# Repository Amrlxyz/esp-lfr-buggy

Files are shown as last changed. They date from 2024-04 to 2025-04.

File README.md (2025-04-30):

# ESP Line Following Robot

**GROUP 48:** 2nd Year Embedded Systems Project (ESP) 2023/24.

Project is in collaboration with 5 teammates: 
- [@Amrlxyz (me)](https://github.com/Amrlxyz) : Main Programmer + 3D CAD Designer 
- [@Hubr1z](https://github.com/Hubr1z) : 2nd Programmer
- [@Sarahelma](https://github.com/Sarahelma) : PCB Designer
- [@nishoujiwojiubuhuine](https://github.com/nishoujiwojiubuhuine) : 3rd Programmer + General Tech 
- [@Giselle-zheng](https://github.com/Giselle-zheng) : Wiring and Electrical

## Gallery

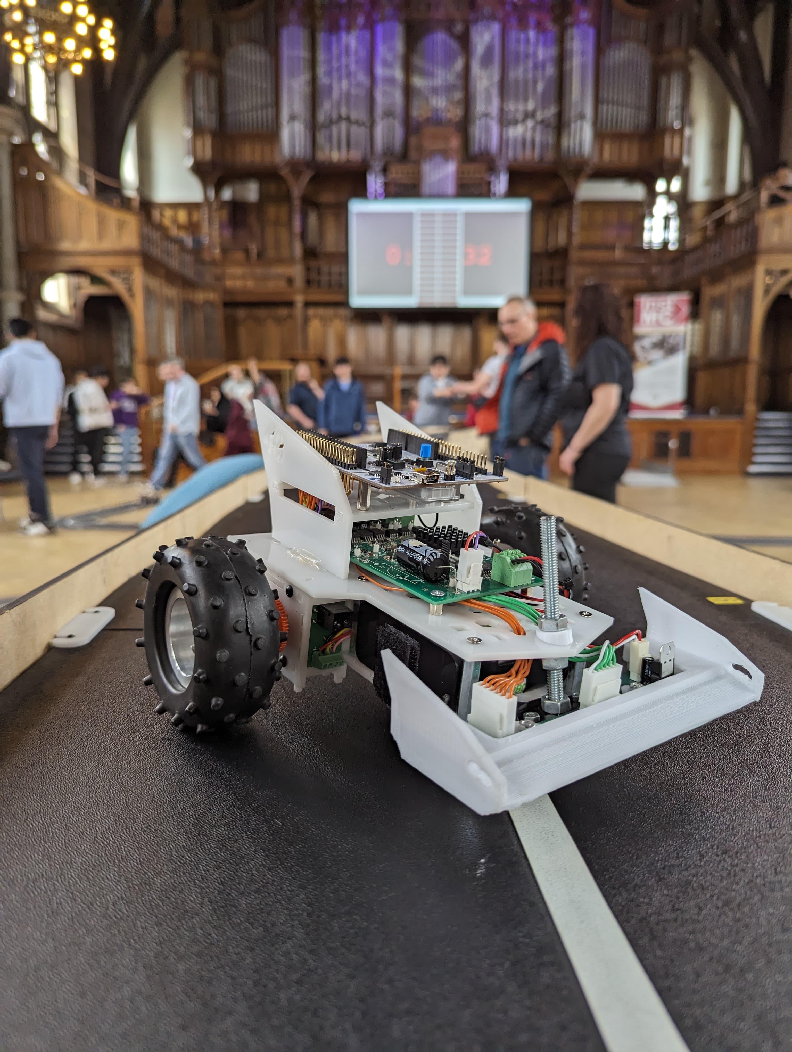
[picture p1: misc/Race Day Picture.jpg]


*Buggy Picture on the final race day*

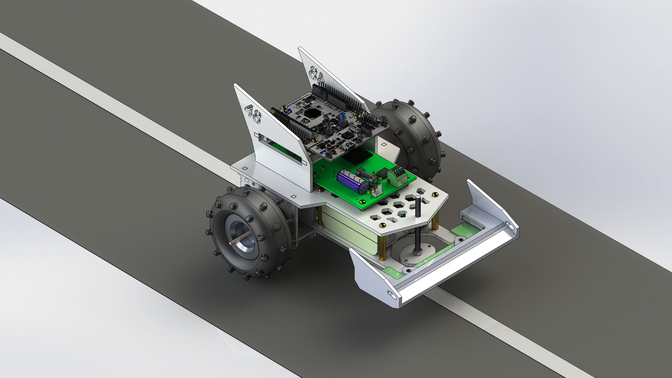
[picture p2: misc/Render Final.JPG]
Buggy Render


*Final Buggy Render Using SolidWorks*

## Achievements

- **ESP 2023/24 Final Race Winner !!!**
- 100% for TDA (Techincal Demonstration A)
- 100% for TDB (Techincal Demonstration B)
- 100% for TDC (Techincal Demonstration C)

## Features

- Mbed v5.15
- Nucleo STM32F401RE 
- Custom Sensor Array PCB
- Array of 6x TCRT5000 IR sensor for line following
- Custom CAD Model Designed in Solidworks

## API Documentation

Link to documentation: [Github Pages](https://amrlxyz.github.io/esp-lfr-buggy/)

## How to Use

### Flashing the MCU

1. Use the wiring diagram to connect the components.
2. Clone the project directly to Keil Studio Cloud.
3. Compile and flash on to the microcontroller.
4. Control the buggy using Bluetooth commands.

### How to run

1. Connect BLE to a phone
2. Place the whole sensor array in the black area of the track
3. Send "calibrate" Command
4. Wait until message is recieved on the phone
5. Place the buggy in the middle of the line
6. Send "line_follow" Command

## Buggy Commands

### Setup

1. Use "Serial Bluetooth Terminal" app on Android
2. Settings -> Send -> Newline -> None
3. Send Commands

### Command Format 

[2/3 Capital Letters] [optional value for certain commands] ['/' -> end character]

Full command list is in main.cpp

__Examples:__

EC/ -> "Execute" "Calibrate"

EF/ -> "Execute" "line_follow"

GSB/ -> Get the speed of both motors

## Linkedin Article

[Article Link](https://www.linkedin.com/pulse/2nd-year-embedded-systems-project-final-race-winner-hakeem-jfuzf)

I might have mentioned a follow-up technical write-up at the end... but life (and distractions) keep happening. We'll see.

## Hello Future UoM 2nd Yr EEE Students

Feel free to use this code as inspiration (at your own risk). Looking back, definitely there are ways to improve it.

If you find the code helpful, feel free to drop a star ⭐ on the repo _(I crave external validation)_

Goodluck!

## Dependencies

Imported 3rd Party Mbed Libraries

- [Driver Board Onboard Battery Monitor](https://os.mbed.com/users/EmbeddedSam/code/Nucleo_F401RE_DS271_Battery_Monitor/) by Sam Walsh
- [QEI Library](https://os.mbed.com/cookbook/QEI) by Aron Berk

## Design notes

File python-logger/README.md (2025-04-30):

# Serial Data Processor

Captures data in the form of Comma Seperated Values from Serial and plots the graph.

This is extensively used for our ESP Line Following Robot / Buggy in which it was used to log and tune PID constants.

Currently, the usage of this code is currently limited only to the application of PID data.

However, adapting to different use case should be as simple as changing the variable names in the list.

## Features

- Automatic logging into a csv file into a /logs folder with date/time
- Live plot and latest data plot option

## Example Plots
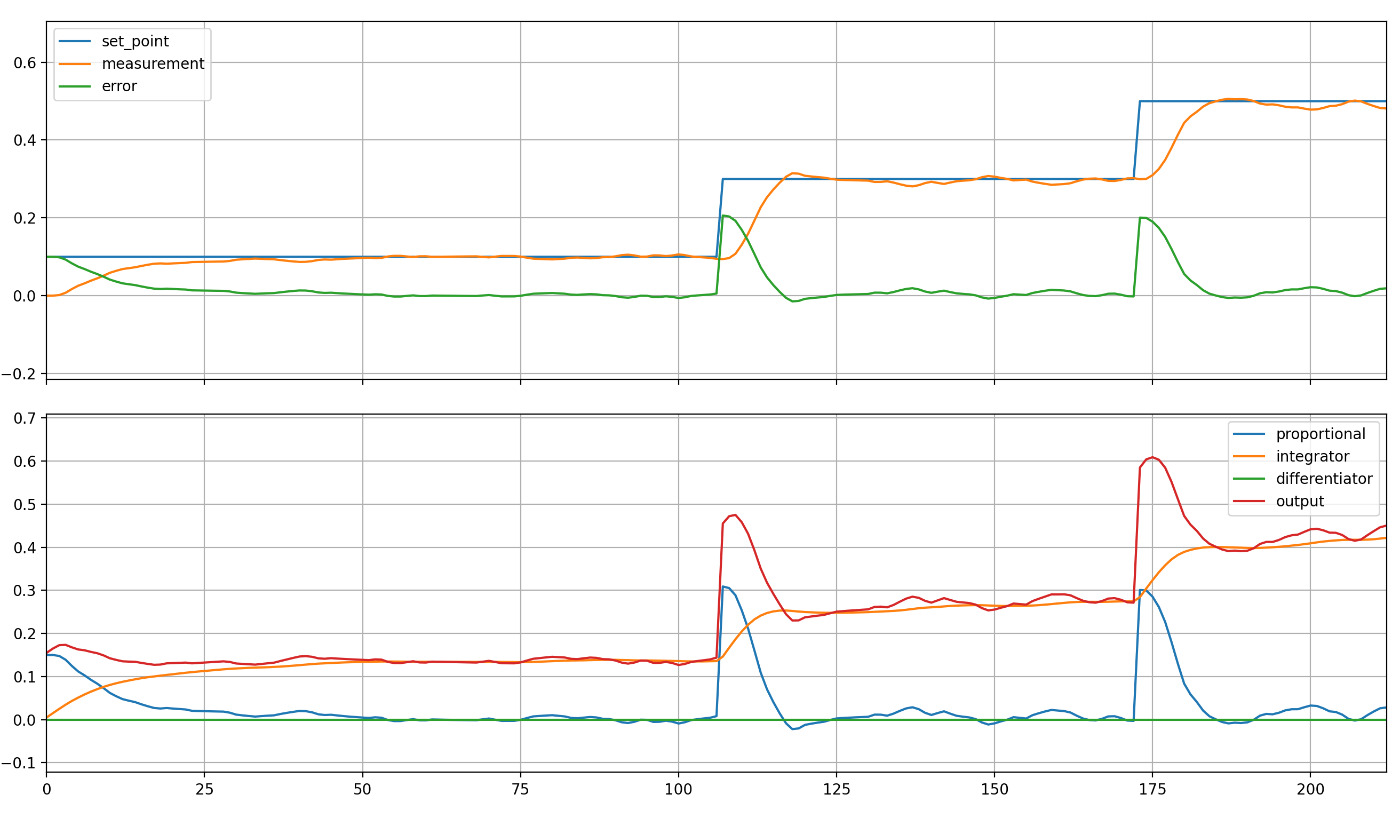
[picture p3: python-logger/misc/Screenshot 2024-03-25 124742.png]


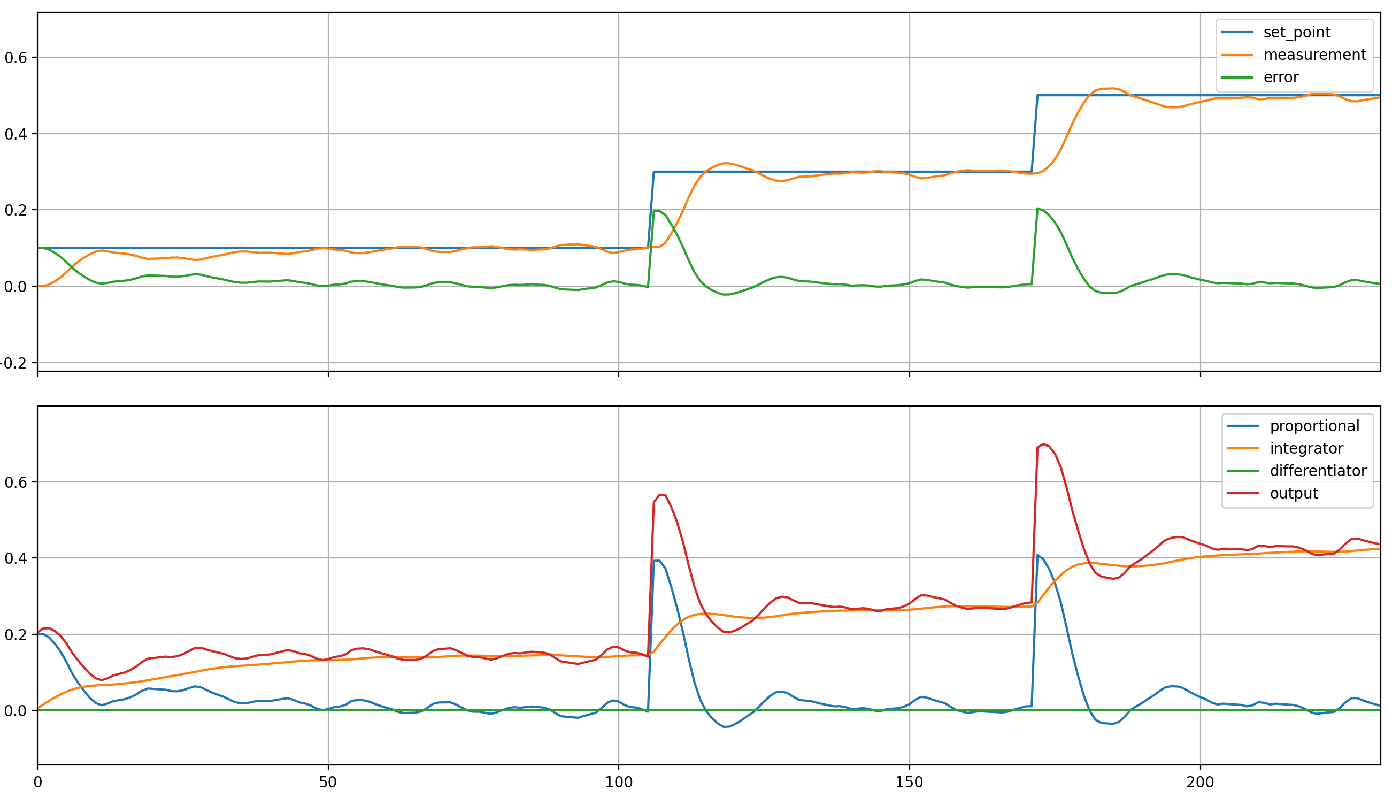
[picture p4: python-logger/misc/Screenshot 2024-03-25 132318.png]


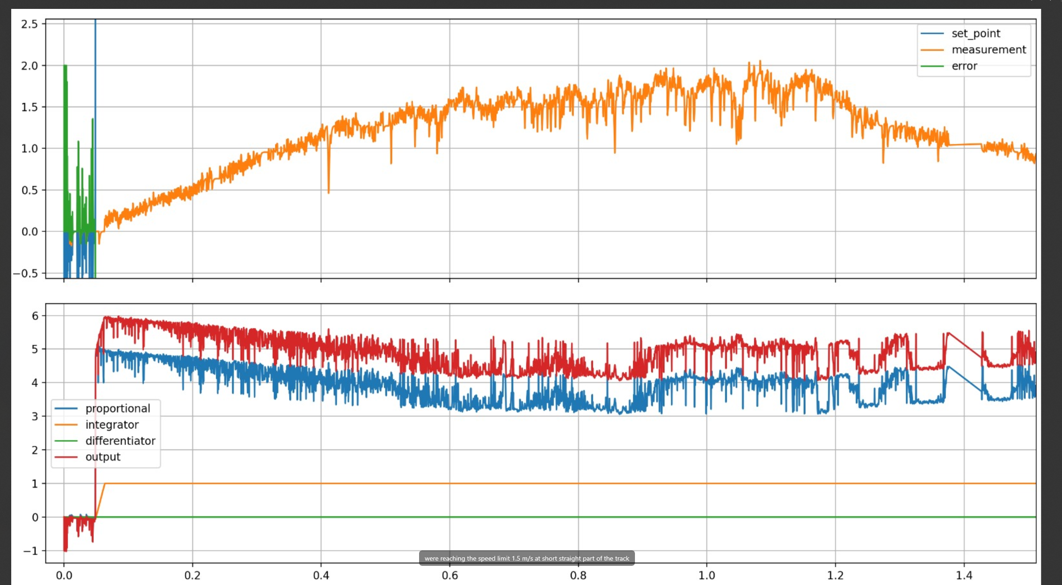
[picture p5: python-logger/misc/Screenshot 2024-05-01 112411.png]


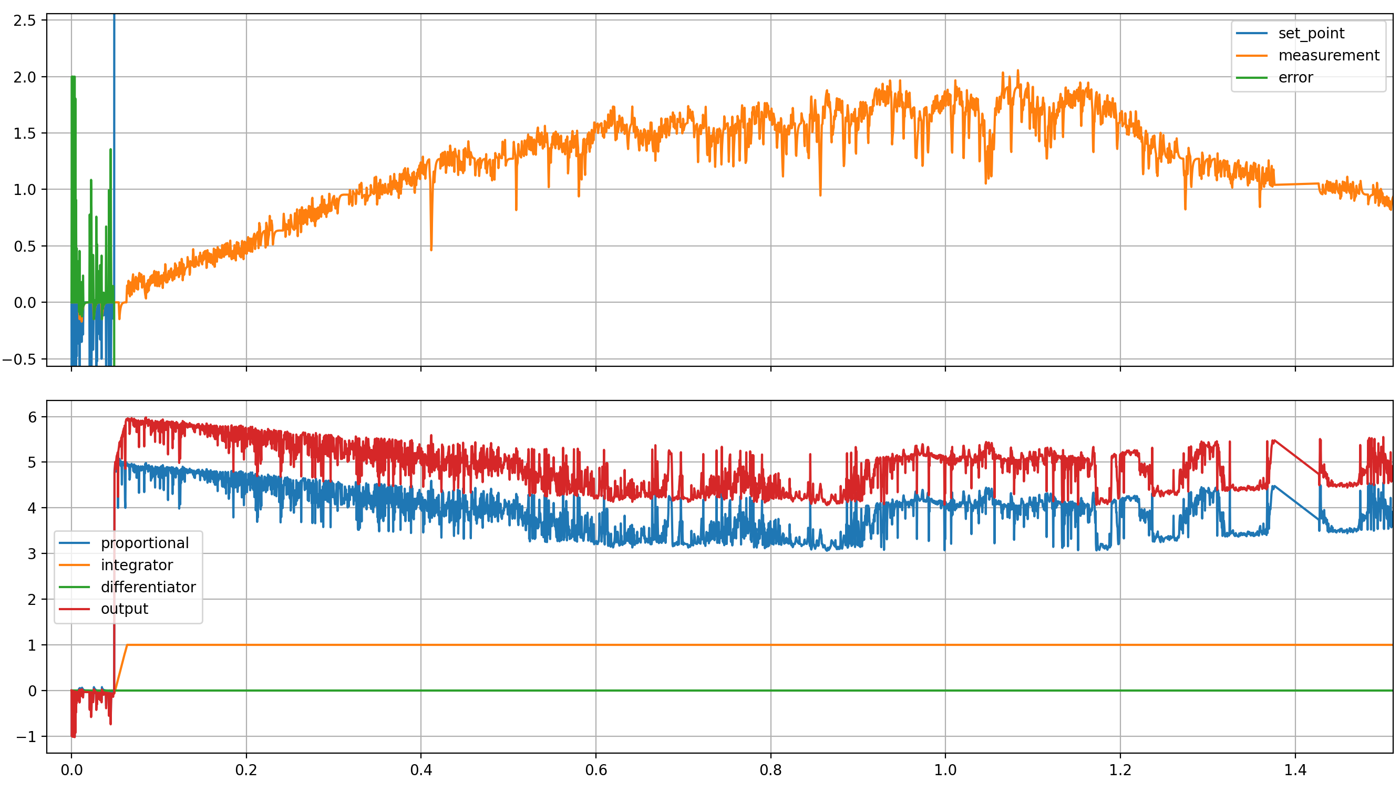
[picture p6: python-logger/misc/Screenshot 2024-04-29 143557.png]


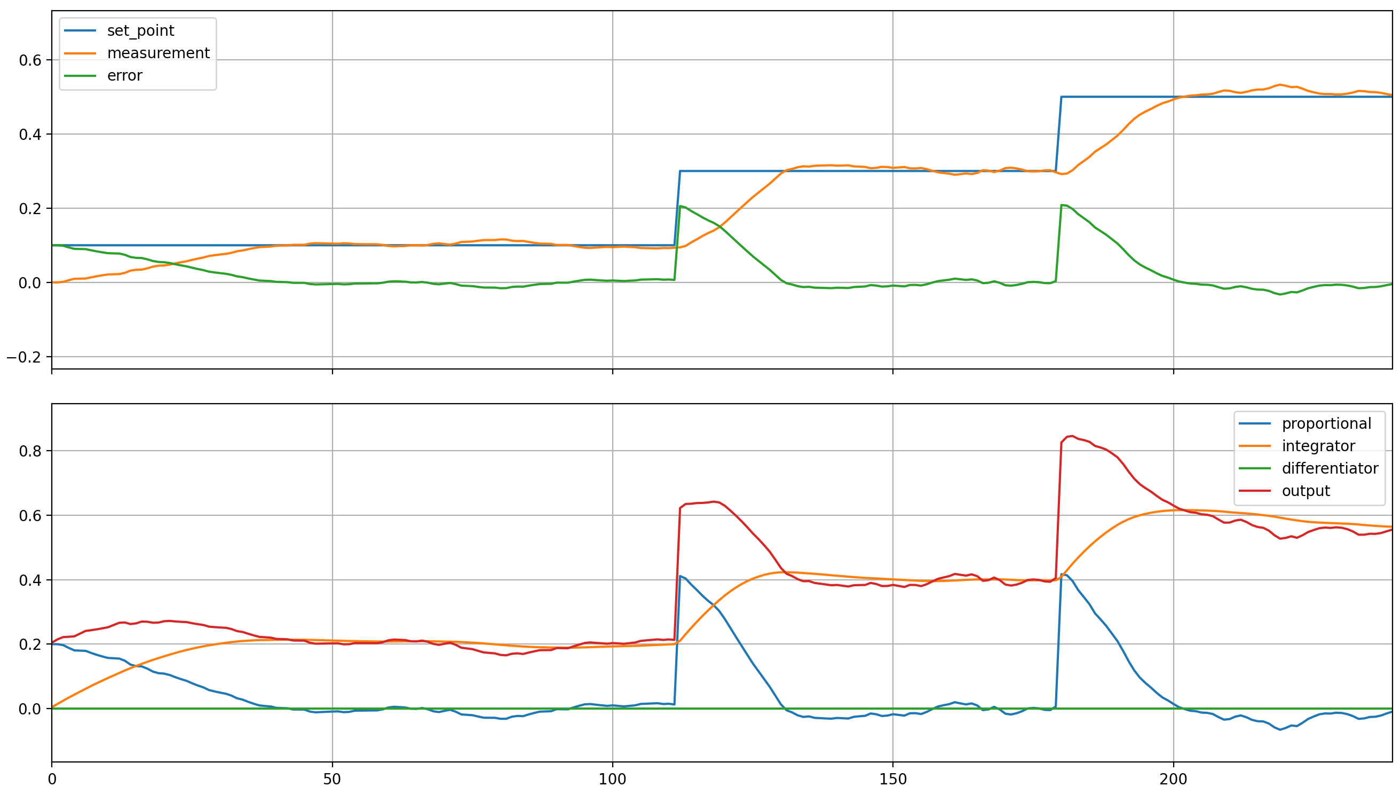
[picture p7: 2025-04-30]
python-logger/misc/Screenshot 2024-03-25 132233.png

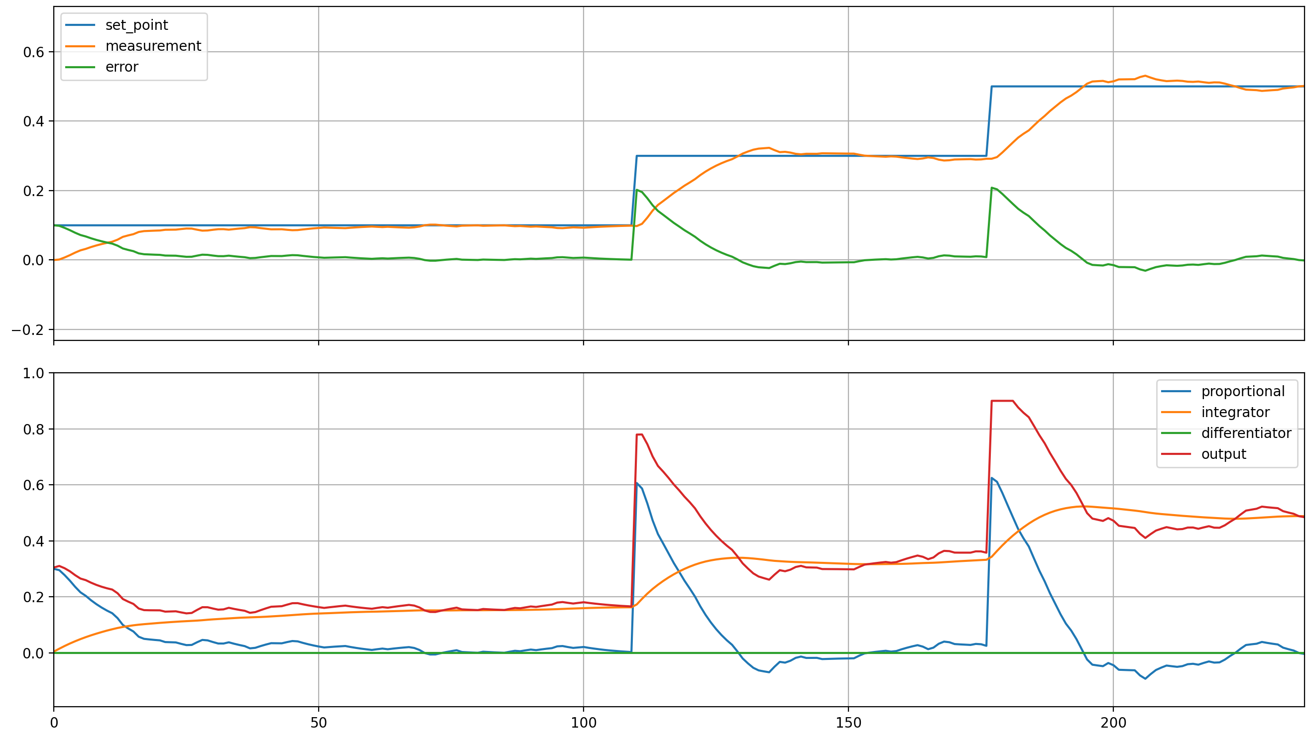
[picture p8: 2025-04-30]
python-logger/misc/Screenshot 2024-03-25 130755.png

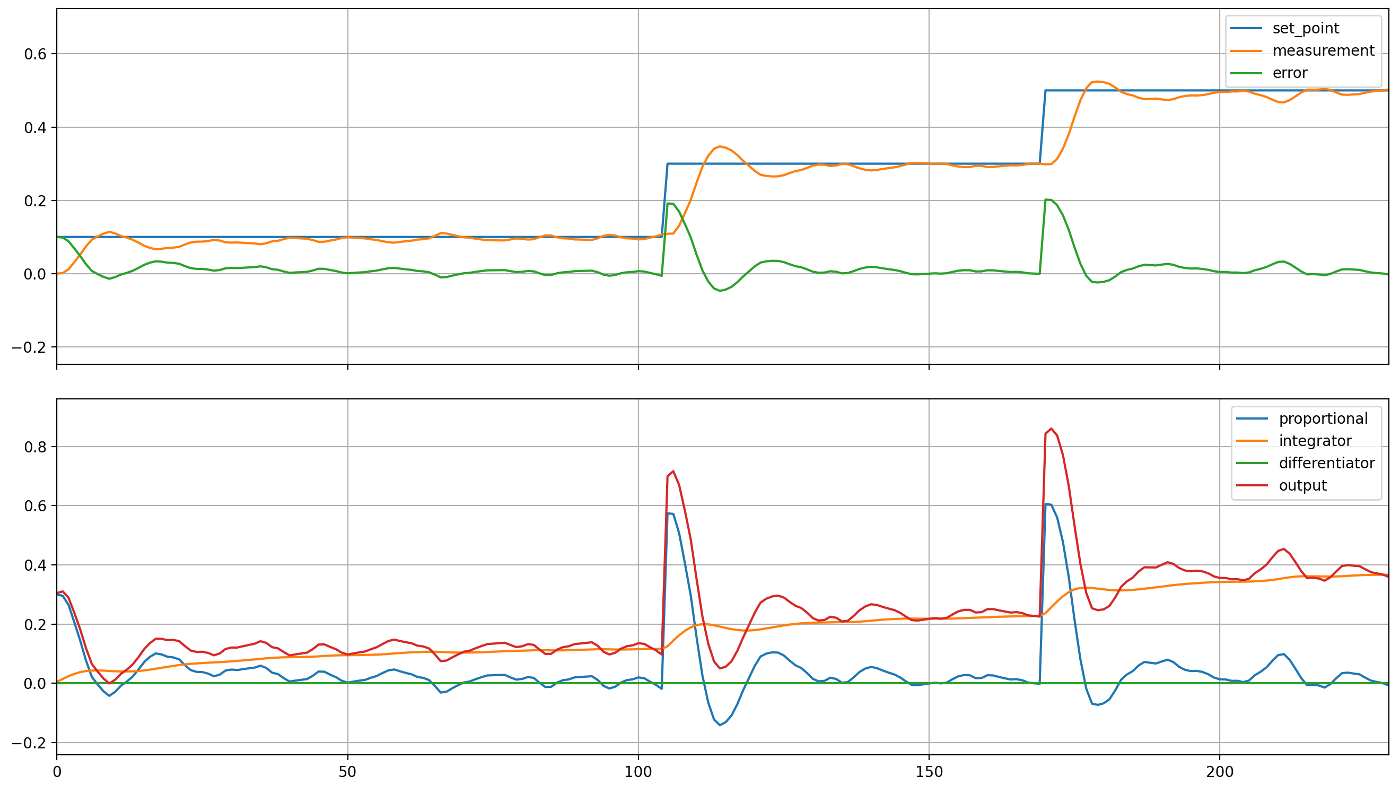
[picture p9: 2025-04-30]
python-logger/misc/Screenshot 2024-03-25 130914.png

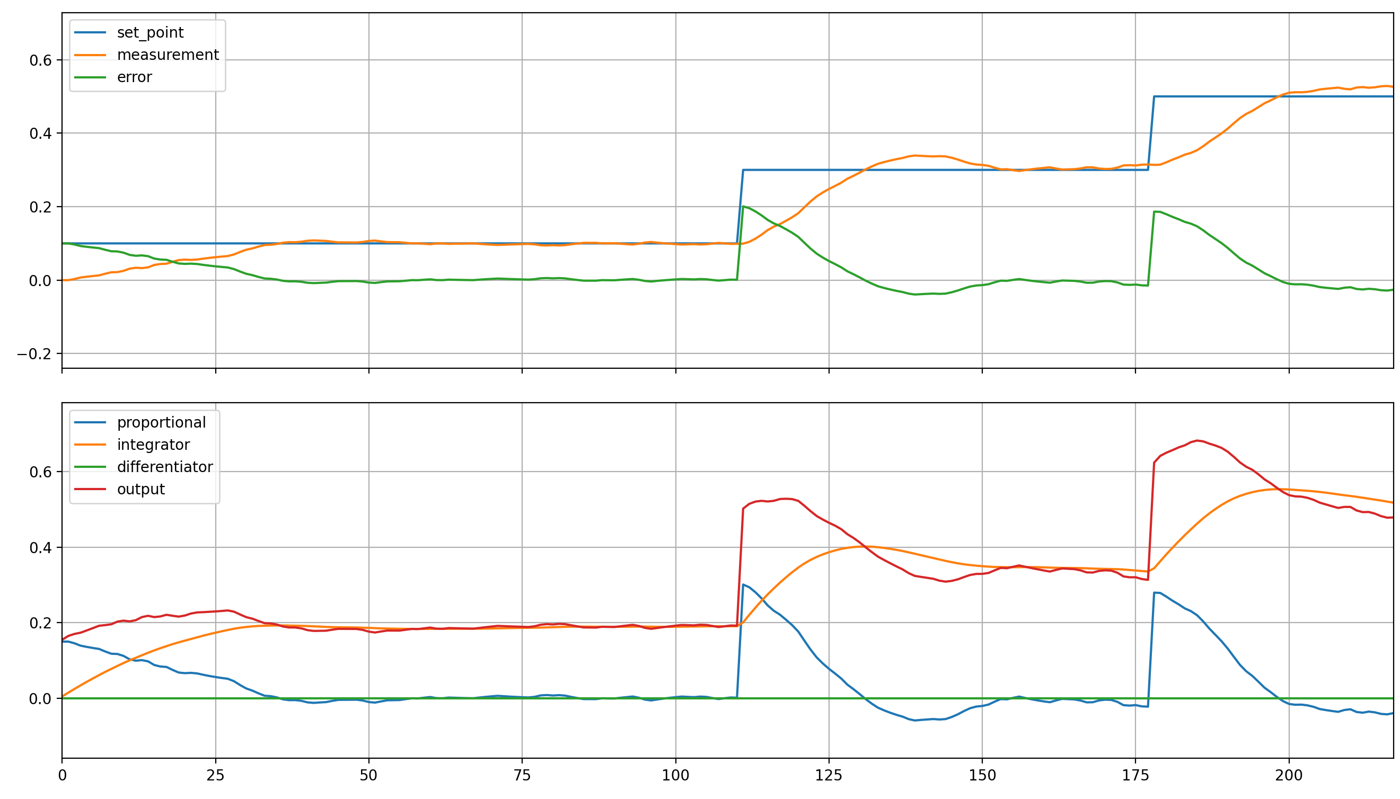
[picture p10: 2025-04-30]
python-logger/misc/Screenshot 2024-03-25 125631.png

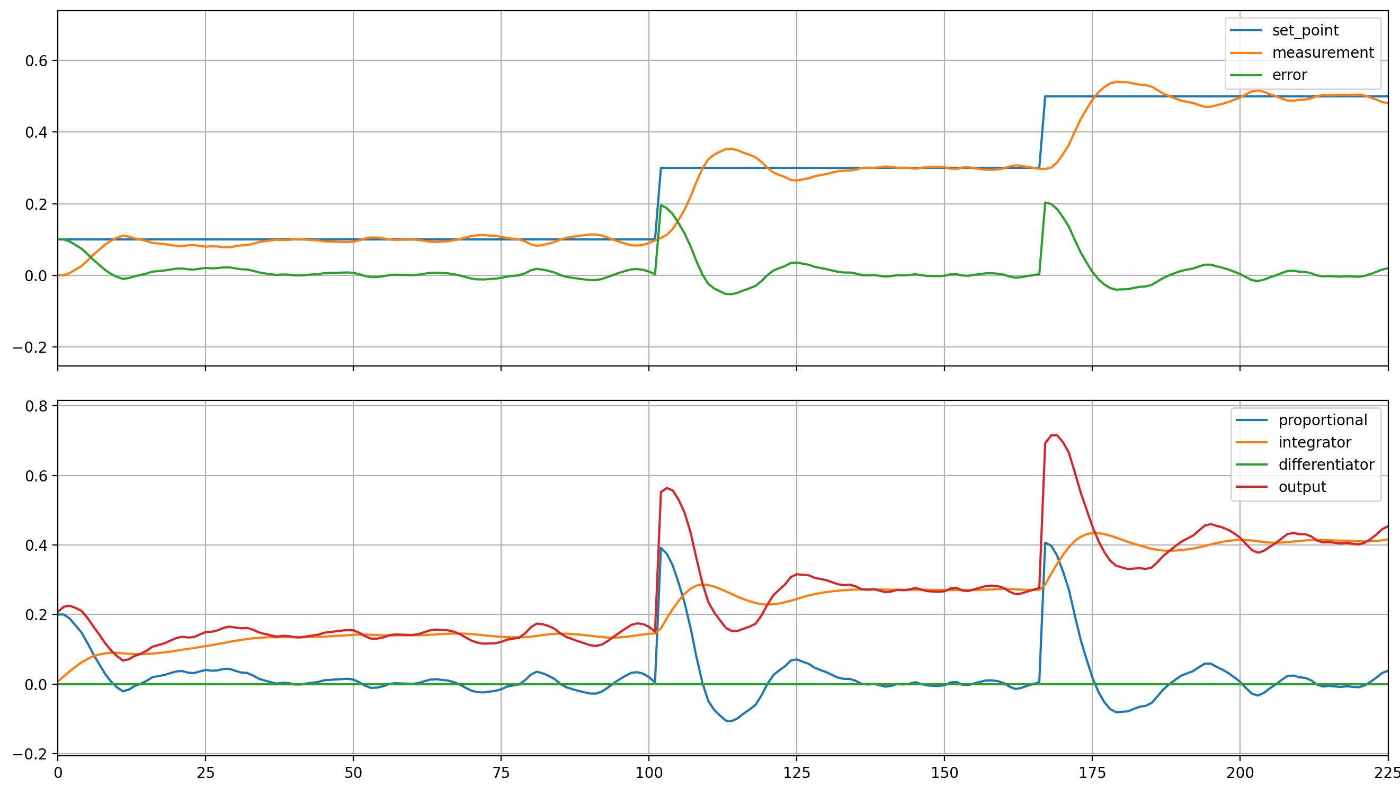
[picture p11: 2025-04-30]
python-logger/misc/Screenshot 2024-03-25 131515.png

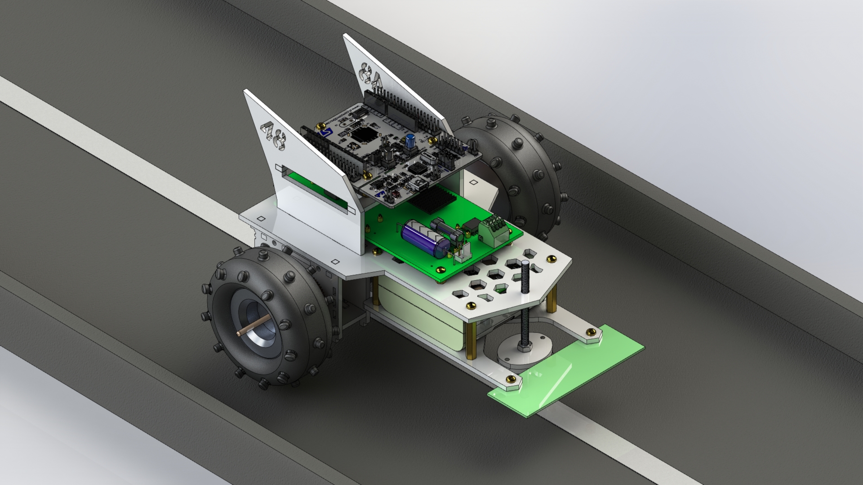
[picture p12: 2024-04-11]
misc/Buggy Render.JPG

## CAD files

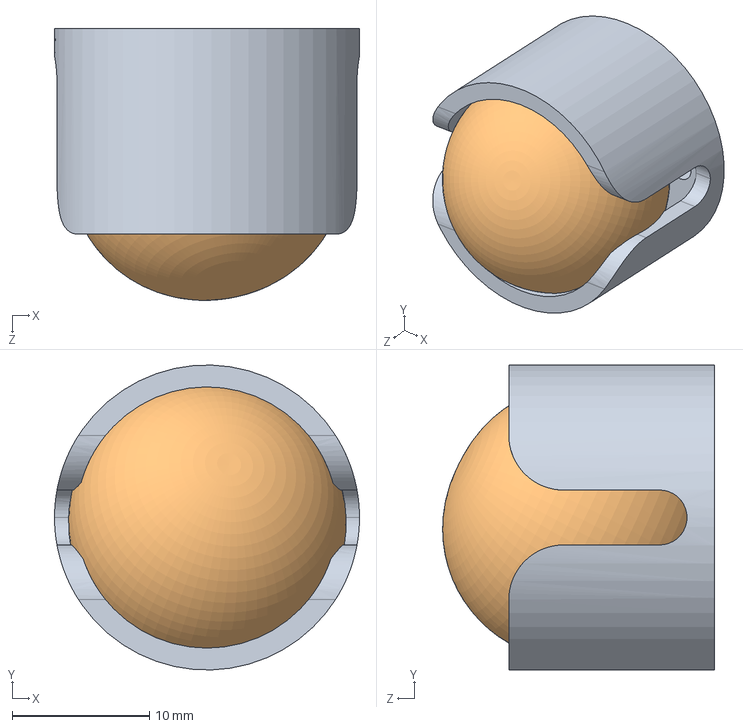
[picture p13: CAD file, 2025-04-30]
hardware/Buggy CAD/Buggy CAD v3/Castor_Assembly/Ball_Housing_Assembly.SLDASM
22.2 x 22.2 x 19.8 mm
Ball Housing
Ball

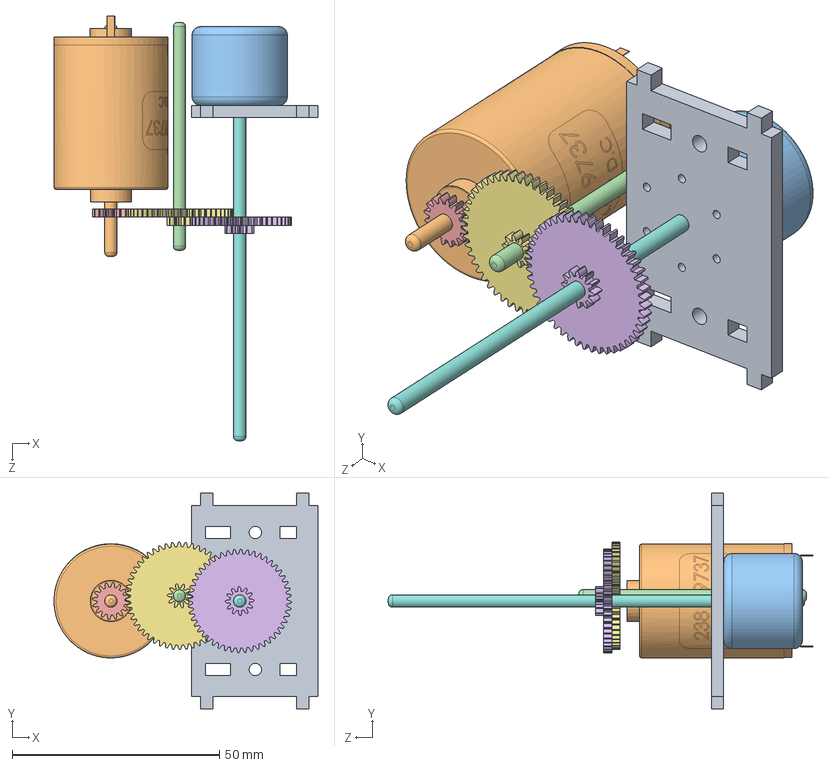
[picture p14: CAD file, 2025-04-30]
hardware/Buggy CAD/Buggy CAD v3/MOTOR_MODULE_2/Gbox Assy.SLDASM
63.8 x 52.1 x 102.5 mm
input side encoder half
Motor
ENCODER
intermediate_axle
spur gear_iso
Gear - 48_12(1)
Gear - 50_10(1)
Axle Long

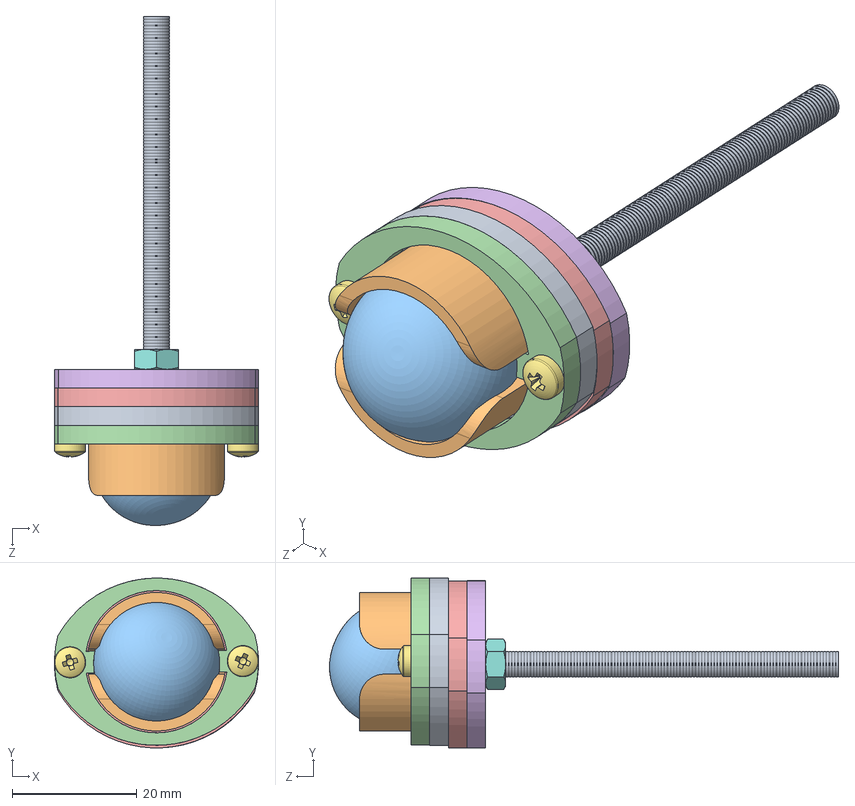
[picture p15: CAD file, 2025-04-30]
hardware/Buggy CAD/Buggy CAD v3/Castor_Assembly/Castor_Assembly.SLDASM
32.7 x 27.3 x 81.7 mm
Ball Housing
Ball
CastorHolder1
CastorHolder2
CastorHolder3
CastorHolder4
pan head cross recess screw_bsi x 2
hex nut style 1 gradeab_bsi
Rod

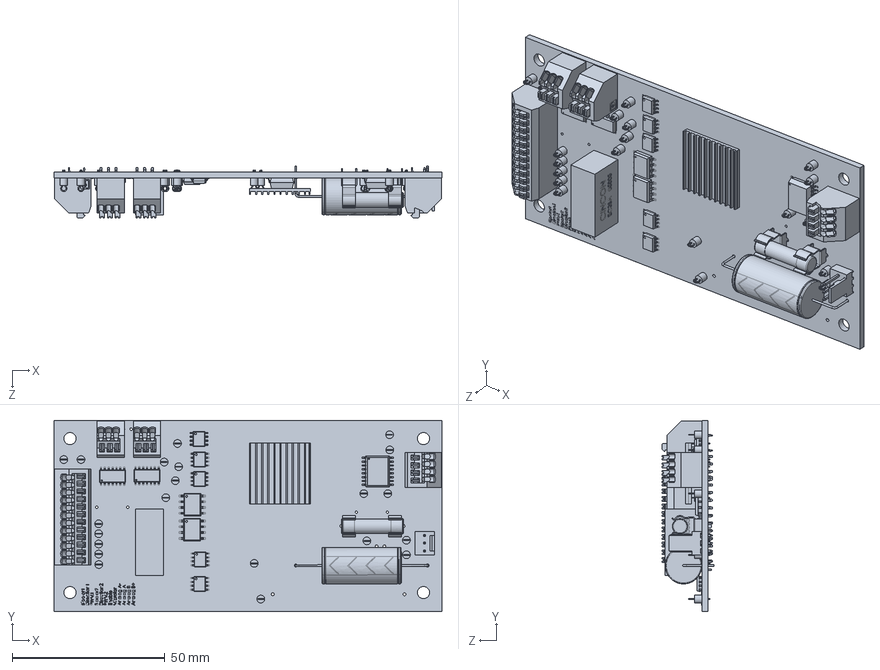
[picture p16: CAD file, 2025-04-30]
hardware/Buggy CAD/Buggy CAD v3/Motor Driver Board Full.SLDPRT
127.2 x 62.8 x 17.1 mm

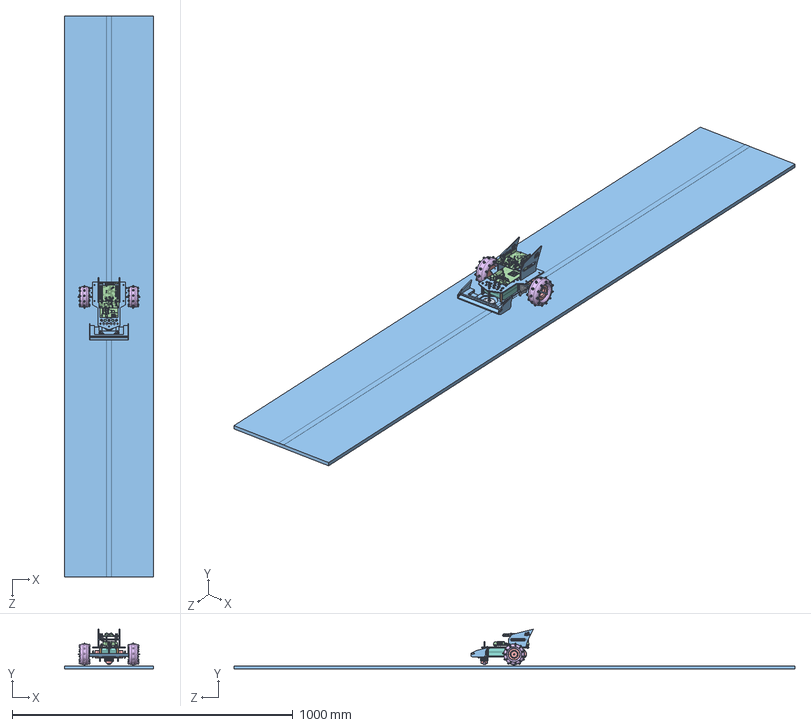
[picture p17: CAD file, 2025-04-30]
hardware/Buggy CAD/Buggy CAD v3/Final Assembly v3.SLDASM
317.0 x 141.8 x 2000.0 mm
Body V3
Motor Driver Board Full
Ball Housing
Ball
CastorHolder1
CastorHolder2
CastorHolder3
CastorHolder4
pan head cross recess screw_bsi x 2
hex nut style 1 gradeab_bsi
Rod
input side encoder half x 2
Motor x 2
ENCODER x 2
intermediate_axle x 2
spur gear_iso x 2
Gear - 48_12(1) x 2
Gear - 50_10(1) x 2
Axle Long x 2
NUCLEO-F401RE
Wheel_Without_Tyre x 2
Tyre(1)(1) x 2
5mm M3 Standoffs x 4
BatteryHolder8Way(1)
10mm M3 Standoffs x 3
30mm M3 Standoffs x 4
M3 Screw and Nut x 2

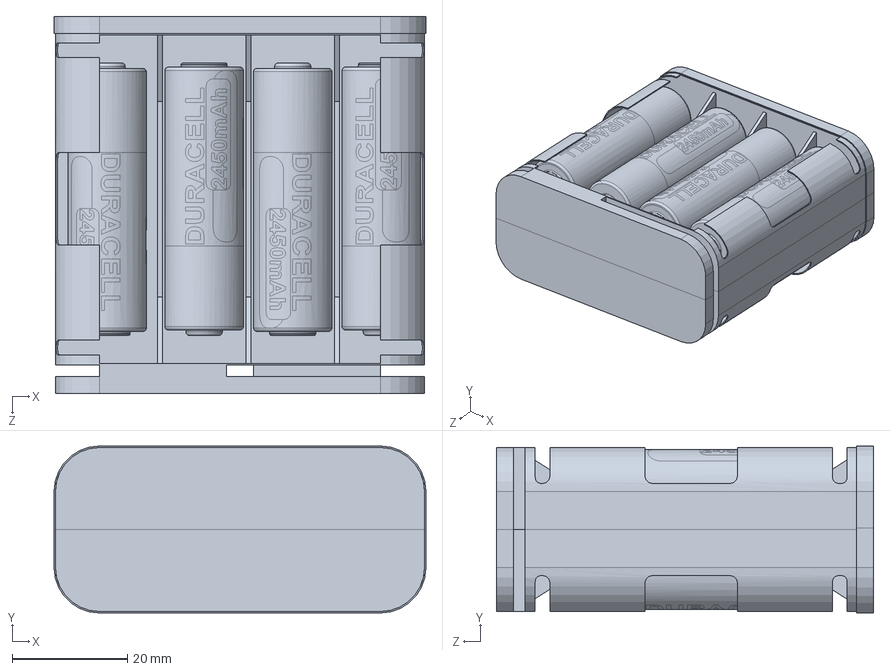
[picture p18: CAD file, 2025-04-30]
hardware/Buggy CAD/Buggy CAD v3/BatteryHolder8Way(1).SLDPRT
64.5 x 29.0 x 65.5 mm

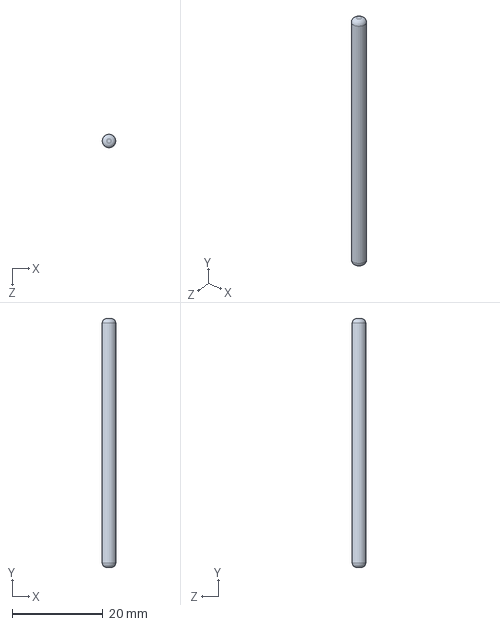
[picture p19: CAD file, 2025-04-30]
hardware/Buggy CAD/Buggy CAD v3/MOTOR_MODULE_2/intermediate_axle.SLDPRT
3.00 x 55.0 x 3.00 mm

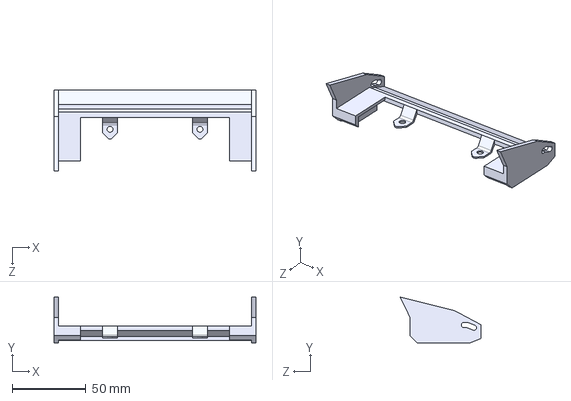
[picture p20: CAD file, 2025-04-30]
hardware/Buggy CAD/Buggy CAD v3/Printed/FrontWingBuggy.STEP
137.0 x 31.1 x 54.8 mm

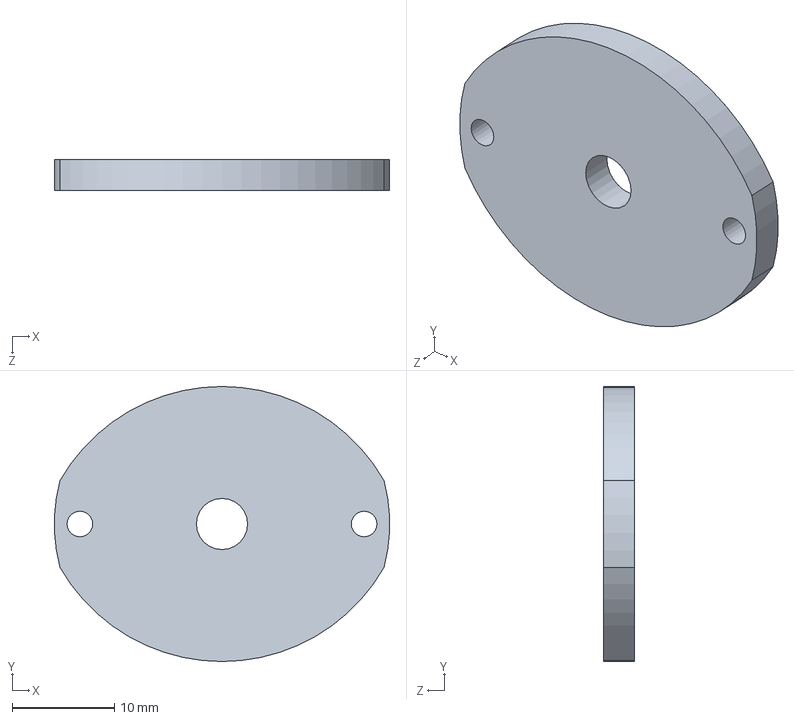
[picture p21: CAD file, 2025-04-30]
hardware/Buggy CAD/Buggy CAD v3/Castor_Assembly/CastorHolder4.SLDPRT
32.7 x 26.9 x 3.00 mm

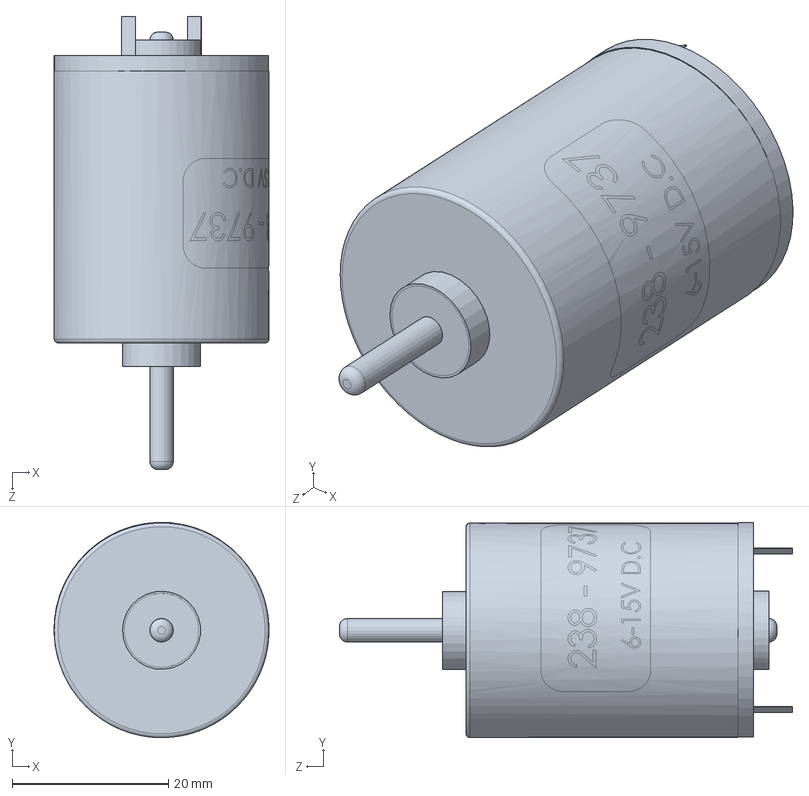
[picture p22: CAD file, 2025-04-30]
hardware/Buggy CAD/Buggy CAD v3/MOTOR_MODULE_2/Motor.SLDPRT
27.5 x 27.6 x 58.0 mm

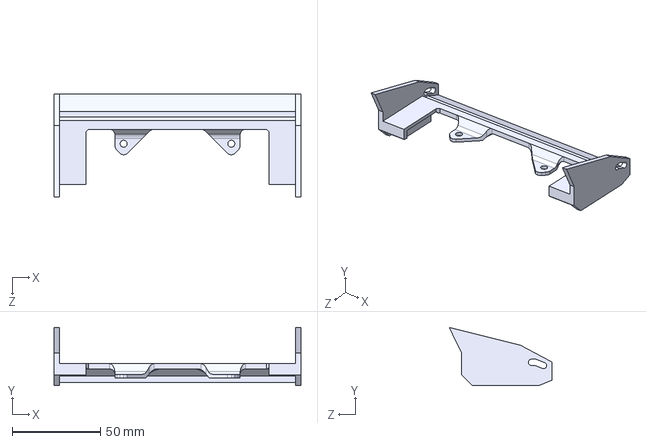
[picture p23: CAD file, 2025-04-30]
hardware/Buggy CAD/Buggy CAD v3/Printed/FrontWingBumper.STEP
140.0 x 33.0 x 58.2 mm

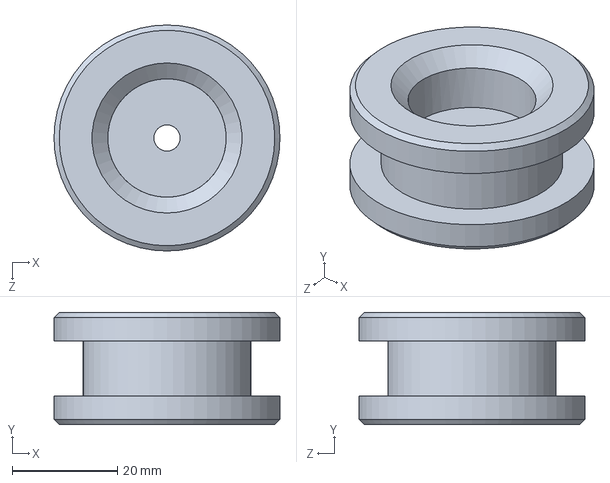
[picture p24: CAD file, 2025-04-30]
hardware/Buggy CAD/Buggy CAD v3/Wheel_Without_Tyre.SLDPRT
43.0 x 21.4 x 43.0 mm

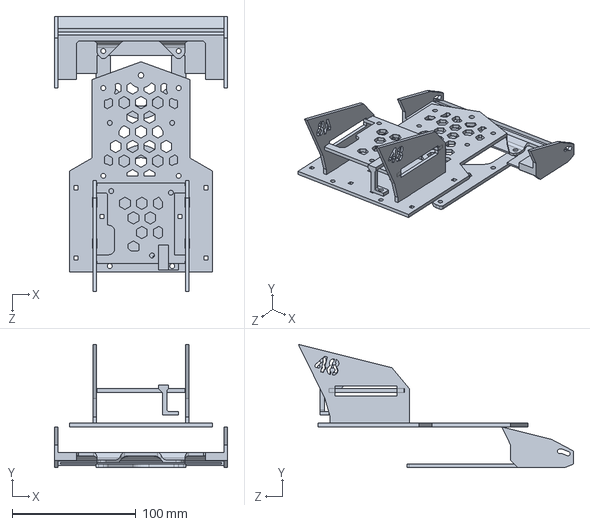
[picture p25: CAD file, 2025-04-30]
hardware/Buggy CAD/Buggy CAD v3/Body V3.SLDPRT
140.0 x 99.8 x 222.9 mm

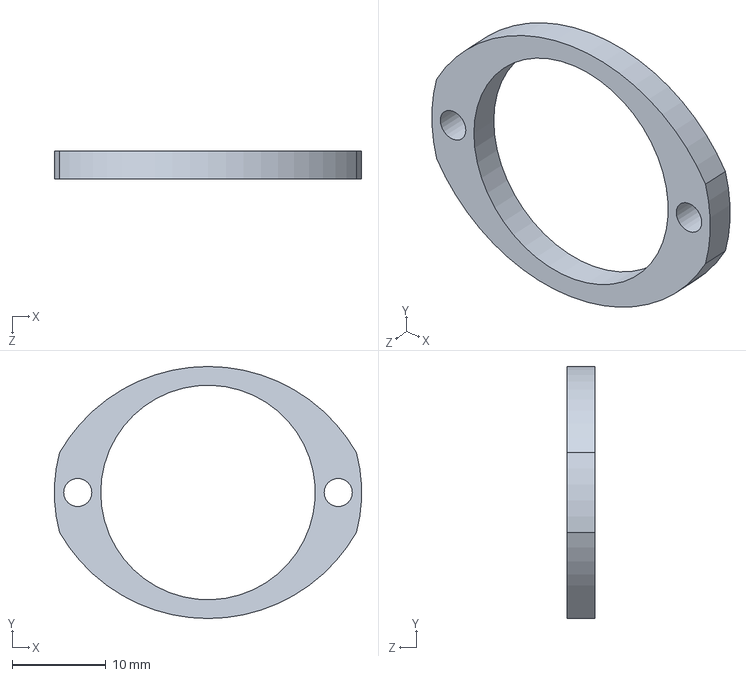
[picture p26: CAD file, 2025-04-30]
hardware/Buggy CAD/Buggy CAD v3/Castor_Assembly/CastorHolder1.SLDPRT
32.7 x 26.8 x 3.00 mm

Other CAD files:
hardware/Buggy CAD/Buggy CAD v3/Castor_Assembly/CastorHolder2.SLDPRT
hardware/Buggy CAD/Buggy CAD v3/Group_48_Holes_Fixed.DXF
hardware/Buggy CAD/Buggy CAD v3/MOTOR_MODULE_2/input side encoder half.SLDPRT
hardware/Buggy CAD/Buggy CAD v3/Printed/30_deg_ramp.STEP
hardware/Buggy CAD/Buggy CAD v1/10mm M3 Standoffs.SLDPRT
hardware/Buggy CAD/Buggy CAD v1/5mm M3 Standoffs.SLDPRT
hardware/Buggy CAD/Buggy CAD v1/Buggy Assembly v1.SLDASM
hardware/Buggy CAD/Buggy CAD v1/Castor_Assembly/Ball Housing.SLDPRT
hardware/Buggy CAD/Buggy CAD v1/Castor_Assembly/Ball.SLDPRT
hardware/Buggy CAD/Buggy CAD v1/Castor_Assembly/CastorHolder2.SLDPRT
hardware/Buggy CAD/Buggy CAD v1/Castor_Assembly/CastorHolder3.SLDPRT
hardware/Buggy CAD/Buggy CAD v1/Castor_Assembly/Castor_Assembly.SLDASM
hardware/Buggy CAD/Buggy CAD v1/Castor_Assembly/Rod.SLDPRT
hardware/Buggy CAD/Buggy CAD v1/Chassis Only.SLDPRT
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

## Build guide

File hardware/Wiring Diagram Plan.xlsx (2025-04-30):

 | LeftMCU
Pin No. | PIN LABEL | CONNECTION | PIN LABEL | CONNECTION
1 | PC_10 |  | PC_11
2 | PC_12 |  | PD_2
3 | VDD |  | E5V | 5V_3
4 | BOOT0 |  | GND | GND_3 |  | COLOR CODE
5 | NC |  | NC |  |  | LEFT (DARKER) | RIGHT
6 | NC |  | IOREF |  |  | LeftMCU | RightMCU
7 | PA_13 |  | RESET |  |  | MOTOR DRIVER
8 | PA_14 |  | 3V3 |  |  | MOTOR L | MOTOR2 R
9 | PA_15 (TIM2C1) |  | 5V | BT VCC |  | SENSOR BOARD
10 | GND |  | GND | BT GND |  | BLUETOOTH
11 | PB_7 |  | GND
12 | PC_13 | X | VIN
13 | PC_14 | X | NC
14 | PC_15 | X | PA_0 (TIM5C1) | CHA
15 | PH_0 | X | PA_1 (TIM5C2) | CHB
16 | PH_1 | X | PA_4 | IN3
17 | VBAT |  | PB_0 | IN4
18 | PC_2 | IN1 | PC_1 | IN5
19 | PC_3 | IN2 | PC_0 | IN6
 | RightMCU
Pin No. | PIN LABEL | CONNECTION | PIN LABEL | CONNECTION
1 | PC_9 |  | PC_8
2 | PB_8 |  | PC_6
3 | PB_9 |  | PC_5
4 | AVDD |  | U5V
5 | GND |  | NC
6 | PA_5 | USED BY LED | PA_12 | BT - TX
7 | PA_6 | JP1a_1 | PA_11 | BT - RX
8 | PA_7 | JP1a_2 | PB_12
9 | PB_6 | JP1a_3 | NC
10 | PC_7 | JP1a_4 | GND
11 | PA_9 | JP1a_5 | PB_2 | OUT1
12 | PA_8 | JP1a_6 | PB_1 | OUT2
13 | PB_10 | Enable | PB_15 | OUT3
14 | PB_4 | MicroLan | PB_14 | OUT4
15 | PB_5 |  | PB_13 | OUT5
16 | PB_3 (TIM2C2) | CHA | AGND
17 | PA_10 | CHB | PC_4 | OUT6
18 | PA_2 (TIM2C3) | X USART | NC
19 | PA_3 (TIM2C4) | X USART | NC
 | JP1a |  | JP8
Pin No. | PIN LABEL | CONNECTION | PIN LABEL | CONNECTION
1 | Bipolar 1 | PA_6 | 4 - Out1R | V+
2 | Direction 1 | PA_7 | 3 - Out1L | V-
3 | PWM 1 | PB_6 | 2 - Out2R | V+
4 | Bipolar 2 | PC_7 | 1 - Out2L | V-
5 | Direction 2 | PA_9
6 | PWM 2 | PA_8
7 | Enable | PB_10
8 | MicroLan | PB_4
9 | Analog A- | Not Important
10 | Analog A+ | Not Important
11 | Analog B- | Not Important
12 | Analog B- | Not Important
 | JP4 |  | JP5
Pin No. | PIN LABEL | CONNECTION | PIN LABEL | CONNECTION
1 | 5V_1 | Enc_5V | GND_1 | Enc_0V
2 | 5V_2 | Enc_5V | GND_2 | Enc_0V
3 | 5V_3 | 5V | GND_3 | GND
 | MOTORL |  | MOTORR
 | PIN LABEL | CONNECTION | PIN LABEL | CONNECTION
 | V+ | Out2R | V+ | Out1R
 | V- | Out2L | V- | Out1L
 | Enc_5V | 5V | Enc_5V | 5V
 | Enc_0V | GND | Enc_0V | GND
 | CHA | PA_2 (TIM2C3) | CHA | PA_0 (TIM5C3)
 | CHB | PA_3 (TIM2C4) | CHB | PA_1 (TIM2C4)
 | SENS_PWR
 | PIN LABEL | CONNECTION
 | 5V | 5V_3
 | GND | GND_3
 |  |  |  |  | Connect the flipped gearbox as if it is with flipped terminals
 | SENS_D_IN |  | SENS_A_OUT | NEEDS ADC
 | PIN LABEL | CONNECTION | PIN LABEL | CONNECTION
 | OUT1 | PB_2 | IN1 | PC_2
 | OUT2 | PB_1 | IN2 | PC_3
 | OUT3 | PB_15 | IN3 | PA_4
 | OUT4 | PB_14 | IN4 | PB_0
 | OUT5 | PB_13 | IN5 | PC_1
 | OUT6 | PC_4 | IN6 | PC_0

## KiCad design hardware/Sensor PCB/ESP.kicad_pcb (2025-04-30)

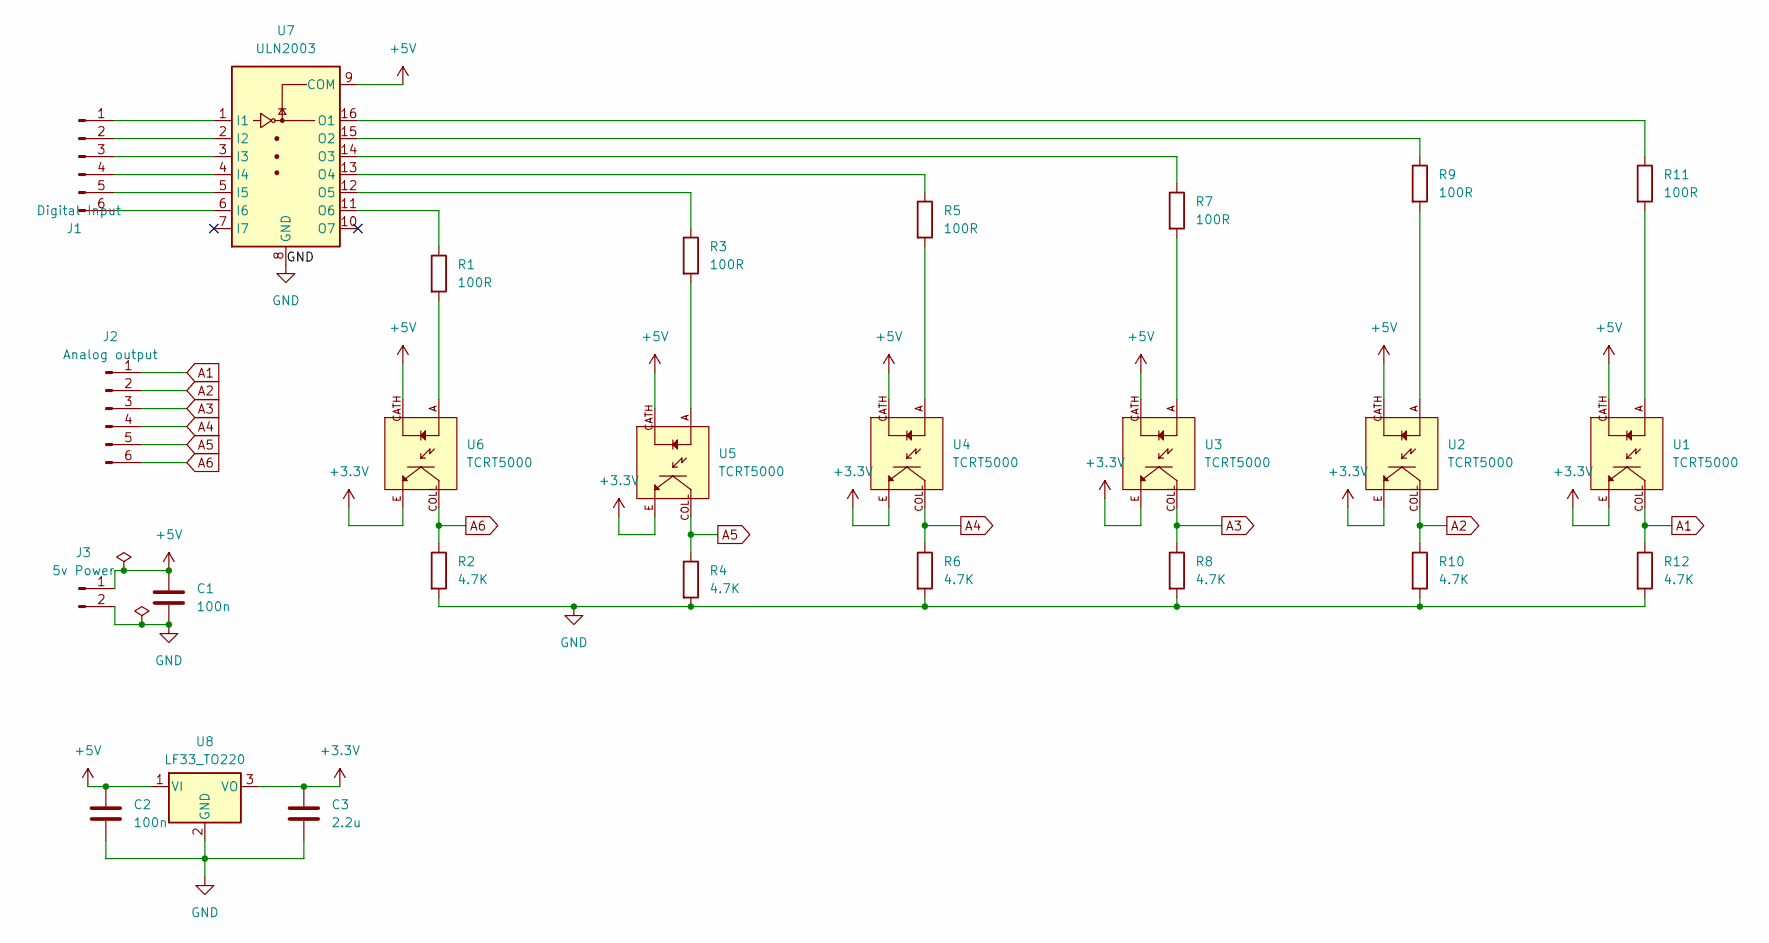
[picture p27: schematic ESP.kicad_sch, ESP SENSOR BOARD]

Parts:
C1, C2: 100n; CP_Radial_D5.0mm_P2.50mm
C3: 2.2u; CP_Radial_D5.0mm_P2.50mm
J1: Digital Input; JST_EH_B6B-EH-A_1x06_P2.50mm_Vertical
J2: Analog output; JST_EH_B6B-EH-A_1x06_P2.50mm_Vertical
J3: 5v Power; JST_ACH_BM02B-ACHSS-GAN-ETF_1x02-1MP_P1.20mm_Vertical
R1, R3, R5, R7, R9: 100R; R_Axial_DIN0207_L6.3mm_D2.5mm_P7.62mm_Horizontal
R2, R4, R6, R8, R10, R12: 4.7K; R_Axial_DIN0207_L6.3mm_D2.5mm_P7.62mm_Horizontal
R11: 100R; R_Axial_DIN0207_L6.3mm_D2.5mm_P5.08mm_Vertical
U1, U2, U3, U4, U5, U6: TCRT5000; OPTO_TCRT5000; PARTREV 1.7
U7: ULN2003; DIP-16_W7.62mm
U8: LF33_TO220; TO-220-3_Vertical

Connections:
+3.3V: C3.1, U1.E, U2.E, U3.E, U4.E, U5.E, U6.E, U8.3 (VO)
+5V: C1.1, C2.1, J3.1, U1.CATH, U2.CATH, U3.CATH, U4.CATH, U5.CATH, U6.CATH, U7.9 (COM), U8.1 (VI)
A1: J2.1, R12.1, U1.COLL
A2: J2.2, R10.1, U2.COLL
A3: J2.3, R8.1, U3.COLL
A4: J2.4, R6.1, U4.COLL
A5: J2.5, R4.1, U5.COLL
A6: J2.6, R2.1, U6.COLL
GND: C1.2, C2.2, C3.2, J3.2, R2.2, R4.2, R6.2, R8.2, R10.2, R12.2, U7.8 (GND), U8.2 (GND)
unnamed: J1.1, U7.1 (I1)
unnamed: J1.2, U7.2 (I2)
unnamed: J1.3, U7.3 (I3)
unnamed: J1.4, U7.4 (I4)
unnamed: J1.5, U7.5 (I5)
unnamed: J1.6, U7.6 (I6)
unnamed: R1.2, U6.A
unnamed: R3.2, U5.A
unnamed: R5.2, U4.A
unnamed: R7.2, U3.A
unnamed: R9.2, U2.A
unnamed: R11.2, U1.A
unnamed: R11.1, U7.16 (O1)
unnamed: R9.1, U7.15 (O2)
unnamed: R7.1, U7.14 (O3)
unnamed: R5.1, U7.13 (O4)
unnamed: R3.1, U7.12 (O5)
unnamed: R1.1, U7.11 (O6)

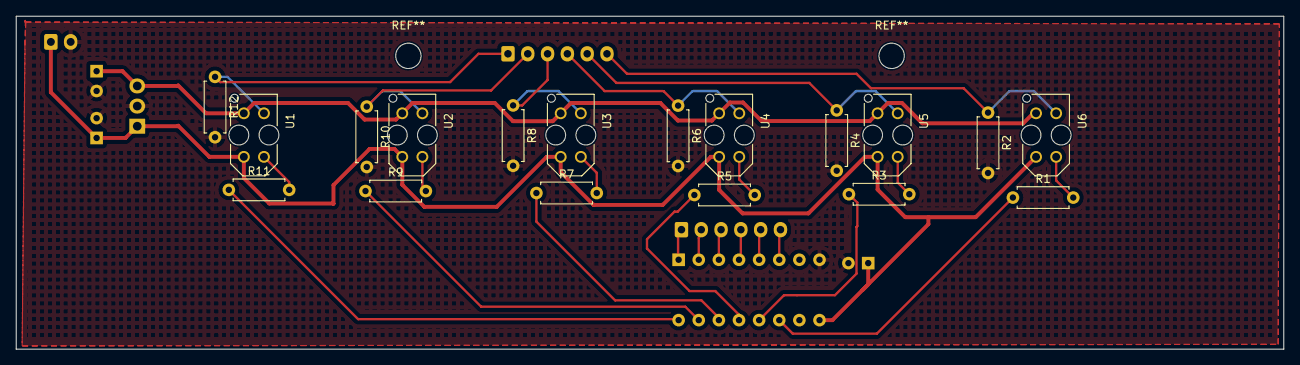
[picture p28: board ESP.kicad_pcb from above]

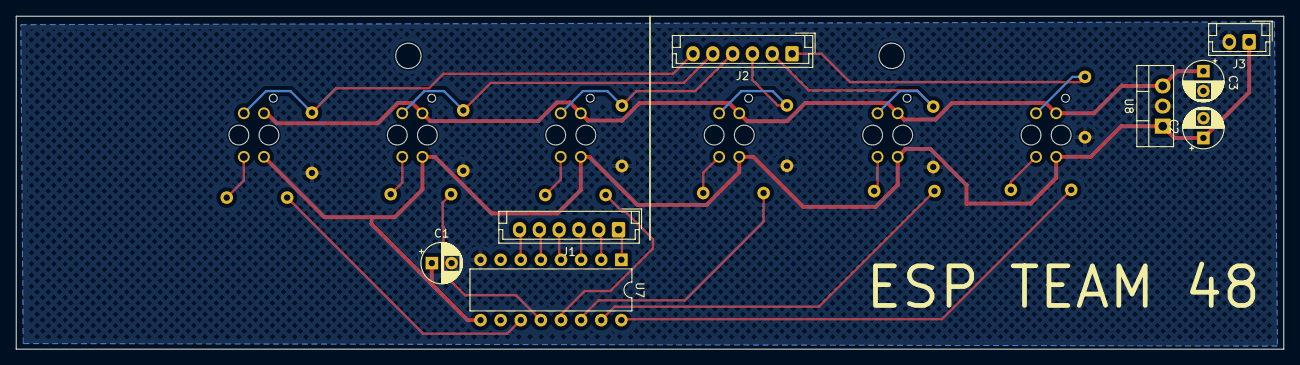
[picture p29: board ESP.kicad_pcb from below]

Board: 2 copper layers, 160.0 x 42.0 mm, 26 parts (8 on the bottom side), 27 nets.

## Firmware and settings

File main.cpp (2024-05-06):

/**
 * @file main.cpp
 * @brief main buggy code
 *
 * This file contains all the buggy logic
 * 
 */

#include "mbed.h"
#include "QEI.h"

#include "constants.h"
#include "pin_assignments.h"
#include "bluetooth.h"
#include "motor.h"
#include "PID.h"
#include "motor_driver_board.h"
#include "sensor_array.h"


/* BT COMMAND CHARS */
enum Bt_cmd_chars
{
    // 1 - cmd types
    ch_execute = 'E',                // E
    ch_get = 'G',                    // G
    ch_set = 'S',                    // S
    ch_continous = 'C',              // C

    // 2 - exec types
    ch_stop = 'S',                   // S
    ch_active_stop = 'X',            // X
    ch_uturn = 'U',                  // U
    ch_encoder_test = 'E',           // E
    ch_motor_pwm_test = 'M',         // M
    ch_straight_test = 'Z',          // C
    ch_square_test = 'Q',            // Q
    ch_PID_test = 'P',               // P
    ch_toggle_led_test = 'L',        // L
    ch_line_follow = 'F',            // F
    ch_static_tracking = 'T',        // T
    ch_line_follow_auto = 'A',       // A
    ch_calibrate = 'C',

    // 2 - data types
    ch_pwm_duty = 'D',               // D
    ch_ticks_cumulative = 'E',       // E
    ch_speed = 'S',                  // S
    ch_gains_PID = 'P',              // P
    ch_tau_PID = 'T',                // T
    ch_current_usage = 'C',          // C
    ch_runtime = 'R',                // R
    ch_loop_time = 'X',              // X
    ch_loop_count = 'Y',             // Y

    // 3 - obj types
    ch_motor_left = 'L',         // L // PID, Encoder Ticks, Velocity
    ch_motor_right = 'R',        // R // PID, Encoder Ticks, Velocity
    ch_motor_both = 'B',         // B
    ch_sensor = 'S',             // S
    ch_no_obj = 'D',             // default case
};


/* BUGGY MODES */
enum Buggy_modes
{
    square_mode,
    straight_test,
    PID_test,
    line_test,
    line_follow,
    task_test,
    task_test_inactive,
    inactive,
    active_stop,
    uturn,
    static_tracking,
    line_follow_auto,
    stop_detect_line,
    calibration,
};


/**
 * @brief Represents the status of a buggy.
 * 
 * This struct holds various parameters related to the state of the buggy, including velocities,
 * angles, distances, and task-specific variables.
 */
struct Buggy_status
{
    float set_velocity;         /**< @brief The set velocity for the buggy. */
    float set_angle;            /**< @brief The set angle for the buggy. */

    float left_set_speed;       /**< @brief The set speed of the left wheel. */
    float right_set_speed;      /**< @brief The set speed of the right wheel. */

    float cumulative_angle_deg; /**< @brief The cumulative angle (in degrees) traveled by the buggy. */
    float distance_travelled;   /**< @brief The distance travelled by the buggy. */

    float lf_line_last_seen;    /**< @brief The position of the last seen line by the left front sensor. */

    // Accel Curve Variables
    float accel_start_distance;
    float accel_start_angle;
    bool is_accelerating;

    // square task variables
    float sq_set_angle;         /**< @brief The set angle for the square task. */
    float sq_set_distance;      /**< @brief The set distance for the square task. */
    int sq_stage;               /**< @brief The current stage of the square task. */
};


/* GLOBAL VARIBLES DECLARATIONS */
volatile bool pc_serial_update = false;
volatile bool bt_serial_update = false;
int ISR_exec_time = 0;
int loop_exec_time = 0;

float bt_float_data[3] = {0};
short int data_log[LOG_SIZE][5] = {0};
int log_index = 0;
char bt_data_sent;
char bt_obj_sent;
float* pid_constants;               // used only for sending datat to bluetooth
float* cal_constants;

Buggy_modes  buggy_mode;          // stores buggy states when performing actions
Buggy_modes  prev_buggy_mode;
Buggy_status buggy_status = {0};

volatile float lf_velocity = LINE_FOLLOW_VELOCITY;


/* OBJECTS DECLARATIONS */
DigitalOut LED(LED_PIN);                    // Debug LED set
Serial pc(USBTX, USBRX, 115200);            // set up serial comm with pc
Timer global_timer;                         // set up global program timer
Ticker control_ticker;
Ticker serial_ticker;
Ticker sensor_ticker;
Timeout logic_timout;

Bluetooth bt(BT_TX_PIN, BT_RX_PIN, BT_BAUD_RATE);     
MotorDriverBoard driver_board(DRIVER_ENABLE_PIN, DRIVER_MONITOR_PIN);
SensorArray sensor_array(SENSOR0_IN_PIN, SENSOR1_IN_PIN, SENSOR2_IN_PIN, SENSOR3_IN_PIN, SENSOR4_IN_PIN, SENSOR5_IN_PIN,
                         SENSOR0_OUT_PIN, SENSOR1_OUT_PIN, SENSOR2_OUT_PIN, SENSOR3_OUT_PIN, SENSOR4_OUT_PIN, SENSOR5_OUT_PIN, SENS_SAMPLE_COUNT, SENS_DETECT_RANGE, SENS_ANGLE_COEFF);
Motor motor_left (MOTORL_PWM_PIN, MOTORL_DIRECTION_PIN, MOTORL_BIPOLAR_PIN, MOTORL_CHA_PIN, MOTORL_CHB_PIN, PULSE_PER_REV, MOTOR_PWM_FREQ, CONTROL_UPDATE_RATE, LP_SPEED_A0, LP_SPEED_B0, LP_SPEED_B1, WHEEL_RADIUS);
Motor motor_right(MOTORR_PWM_PIN, MOTORR_DIRECTION_PIN, MOTORR_BIPOLAR_PIN, MOTORR_CHA_PIN, MOTORR_CHB_PIN, PULSE_PER_REV, MOTOR_PWM_FREQ, CONTROL_UPDATE_RATE, LP_SPEED_A0, LP_SPEED_B0, LP_SPEED_B1, WHEEL_RADIUS);
PID PID_motor_left (PID_M_L_KP, PID_M_L_KI, PID_M_L_KD, PID_M_TAU, PID_M_MIN_OUT, PID_M_MAX_OUT, PID_M_MIN_INT, PID_M_MAX_INT, CONTROL_UPDATE_PERIOD);
PID PID_motor_right(PID_M_R_KP, PID_M_R_KI, PID_M_R_KD, PID_M_TAU, PID_M_MIN_OUT, PID_M_MAX_OUT, PID_M_MIN_INT, PID_M_MAX_INT, CONTROL_UPDATE_PERIOD);
PID PID_angle (PID_A_KP, PID_A_KI, PID_A_KD, PID_A_TAU, PID_A_MIN_OUT, PID_A_MAX_OUT, PID_A_MIN_INT, PID_A_MAX_INT, CONTROL_UPDATE_PERIOD);
PID PID_sensor(PID_S_KP, PID_S_KI, PID_S_KD, PID_S_TAU, PID_S_MIN_OUT, PID_S_MAX_OUT, PID_S_MIN_INT, PID_S_MAX_INT, SENSOR_UPDATE_PERIOD);


// Helper Function Prototypes:
void stop_motors(void);                                                 ///< Set pwm dc to 0 for both motors
void update_buggy_status(int tick_count_left, int tick_count_right);    ///< Update buggy status variables
void reset_everything(void);                                            ///< Reset all buggy values and all objects variables
bool bt_parse_rx(char* rx_buffer);                                      ///< Parse recieved bluetooth data
void control_update_ISR(void);                                          ///< ISR updating the control algorithm
void serial_update_ISR(void);                                           ///< ISR to update flag to send data to pc/bt in main()
void stop_detect_ISR(void);                                     
void bt_send_data(void);                                                ///< Send data to the bt module
void pc_send_data(void);                                                ///< Send data to the pc
void sensor_update_ISR();
void slow_accel_ISR(void);


/* MAIN FUNCTION */
int main()
{
    buggy_mode = inactive;
    buggy_mode = inactive;

    while (!bt.is_ready()) {};          // while bluetooth not ready, loop and do nothing

    sensor_array.set_all_led_on(true);

    global_timer.start();                                                           // Starts the global program timer
    sensor_ticker.attach_us(&sensor_update_ISR, SENSOR_UPDATE_PERIOD_US);           // Starts the control ISR update ticker
    control_ticker.attach_us(&control_update_ISR, CONTROL_UPDATE_PERIOD_US);        // Starts the control ISR update ticker
    serial_ticker.attach(&serial_update_ISR, SERIAL_UPDATE_PERIOD);                 // Starts the control ISR update ticker
    
    while (1)
    {
        int curr_time = global_timer.read_us();

        /* --- START OF COMMAND PROCESSING --- */
        if (bt.data_recieved_complete()) 
        {
            char* rx_buf = bt.get_rx_buffer(); 
            if (!bt_parse_rx(rx_buf))
            {
                bt.send_fstring("Err: %s", rx_buf);
            }
            bt.reset_rx_buffer();
        }

        if (pc.readable())
        {
            switch (pc.getc()) 
            {
            case 'r':
                reset_everything();
                buggy_mode = static_tracking;
                break;
            case 's':
                buggy_mode = inactive;
                stop_motors();
                break;
            case 'D':
                buggy_mode = inactive;
                for(int i = 0; i < log_index; i++)
                {
                    pc.printf("%.5f,%.3f,%.3f,%.3f,%.3f,%.3f\n",
                                    (i * CONTROL_UPDATE_PERIOD),
                                    (float) (data_log[i][0] / 1000.0), //= set_point
                                    (float) (data_log[i][1] / 1000.0), //= measurement
                                    (float) (data_log[i][2] / 1000.0), //= propotional
                                    (float) (data_log[i][3] / 1000.0), //= integrator
                                    (float) (data_log[i][4] / 1000.0)); //= differentiator
                }
                log_index = 0;
                break;
            default:
                break;
            }

        }
        /* ---  END OF COMMAND PROCESSING  --- */


        /* --- START OF BUGGY ACTIONS/STATE LOGIC CODE --- */ 
        update_buggy_status(motor_left.get_tick_count(), motor_right.get_tick_count());

        // Buggy mode transition code
        if (buggy_mode != prev_buggy_mode)
        {
            driver_board.set_enable(buggy_mode != inactive && 
                                    buggy_mode != task_test_inactive);

            switch (buggy_mode)
            {
                case PID_test:
                    reset_everything();
                    pid_constants = PID_motor_left.get_constants();
                    bt.send_fstring("P:%.2f,I:%.2f", pid_constants[0], pid_constants[1]);
                    bt.send_fstring("D:%.2f,T:%.2f\n", pid_constants[2], pid_constants[3]);
                    buggy_status.set_angle = 0;
                    buggy_status.set_velocity = 0.0;
                    break;
                case square_mode:
                case straight_test:
                    reset_everything();
                    break;
                case task_test:
                case task_test_inactive:
                    bt.set_continous(true);
                    break;
                case uturn:
                    reset_everything();
                    buggy_status.set_angle = UTURN_ANGLE;
                    buggy_status.set_velocity = 0.0;
                    break;
                case static_tracking:
                    reset_everything();
                    pid_constants = PID_sensor.get_constants();
                    bt.send_fstring("\nP:%.3f\nI:%.3f\n", pid_constants[0], pid_constants[1]);
                    bt.send_fstring("D:%.3f\nT:%.3f\n", pid_constants[2], pid_constants[3]);
                    buggy_status.set_angle = 0;
                    buggy_status.set_velocity = 0.0;
                    break;
                case line_follow_auto:
                case line_follow:
                    reset_everything();

                    // if (!sensor_array.is_line_detected())
                    // {
                    //     buggy_mode = inactive;
                    //     bt.send_fstring("Line undetected\n", global_timer.read());
                    //     break;
                    // }
                    
                    pid_constants = PID_sensor.get_constants();
                    bt.send_fstring("T:%.3f\n", global_timer.read());
                    bt.send_fstring("\nP:%.3f\nI:%.3f\n", pid_constants[0], pid_constants[1]);
                    bt.send_fstring("D:%.3f\nT:%.3f\n", pid_constants[2], pid_constants[3]);

                    buggy_status.set_angle = 0;
                    buggy_status.set_velocity = lf_velocity / SLOW_ACCEL_DIVIDER;

                    buggy_status.accel_start_angle = buggy_status.cumulative_angle_deg;
                    buggy_status.accel_start_distance = buggy_status.distance_travelled;
                    buggy_status.is_accelerating = false;
                    logic_timout.attach(&slow_accel_ISR, SLOW_ACCEL_TIME);
                    break;
                case active_stop:
                    reset_everything();
                    buggy_status.set_angle = 0;
                    buggy_status.set_velocity = 0.0;
                    bt.send_fstring("T:%.3f\n", global_timer.read());
                    break;
                case stop_detect_line:
                    reset_everything();
                    logic_timout.attach(&stop_detect_ISR, STOP_DETECT_TIME);
                    buggy_status.set_angle = 0;
                    buggy_status.set_velocity = 0.0;
                    break;
                case calibration:
                    reset_everything();
                    sensor_array.calibrate_sensors();
                    cal_constants = sensor_array.get_calibration_constants();
                    for (int i = 0; i < 6; i++)
                    {
                        bt.send_fstring("%d:%.4f\n", i, cal_constants[i]);
                    }
                    buggy_mode = inactive;
                    break;
                default:
                    break;
            }            
            prev_buggy_mode = buggy_mode;
        }

        // Buggy mode continous logic
        switch (buggy_mode) 
        {   
            case inactive:
                driver_board.disable();
                stop_motors();
                break;
            case square_mode:
                switch (buggy_status.sq_stage)
                {
                    case 0:
                        buggy_status.sq_set_distance += SQUARE_DISTANCE;
                        buggy_status.set_angle = buggy_status.sq_set_angle;
                        buggy_status.set_velocity = SQUARE_VELOCITY_SET;
                        buggy_status.sq_stage++;
                        break;
                    case 7:
                    case 1:
                    case 3:
                    case 5:
                        if (buggy_status.distance_travelled >= buggy_status.sq_set_distance) // wait to move 1m then, start turning right
                        {
                            if (buggy_status.sq_stage == 7)
                            {
                                buggy_status.sq_set_angle += SQUARE_TURNING_RIGHT_ANGLE;
                            }
                            buggy_status.sq_set_angle += SQUARE_TURNING_RIGHT_ANGLE;
                            buggy_status.set_angle = buggy_status.sq_set_angle;
                            buggy_status.set_velocity = 0;
                            buggy_status.sq_stage++;
                        }
                        break;
                    case 2:
                    case 4:
                    case 6:
                    case 8:
                        if (buggy_status.cumulative_angle_deg >= buggy_status.sq_set_angle) // wait to turn 90 and start moving straight
                        {
                            buggy_status.sq_set_distance += SQUARE_DISTANCE;
                            buggy_status.set_angle = buggy_status.sq_set_angle;
                            buggy_status.set_velocity = SQUARE_VELOCITY_SET;
                            buggy_status.sq_stage++;
                        }
                        break;
                    case 9:
                    case 11:
                    case 13:
                        if (buggy_status.distance_travelled >= buggy_status.sq_set_distance) // wait to move 1m then, start turning left
                        {
                            buggy_status.sq_set_angle -= SQUARE_TURNING_LEFT_ANGLE;
                            buggy_status.set_angle = buggy_status.sq_set_angle;
                            buggy_status.set_velocity = 0;
                            buggy_status.sq_stage++;
                        }
                        break;
                    case 10:
                    case 12:
                    case 14:
                        if (buggy_status.cumulative_angle_deg <= buggy_status.sq_set_angle) // wait to turn -90 and start moving straight
                        {
                            buggy_status.sq_set_distance += SQUARE_DISTANCE;
                            buggy_status.set_angle = buggy_status.sq_set_angle;
                            buggy_status.set_velocity = SQUARE_VELOCITY_SET;
                            buggy_status.sq_stage++;
                        }
                        break;
                    case 15:
                        if (buggy_status.distance_travelled >= buggy_status.sq_set_distance)  // Stop
                        {
                            buggy_mode = inactive;
                            stop_motors();
                            buggy_status.sq_stage = 0;
                        }
                        break;
                    default:
                        break;
                }
                break;
            case PID_test:
                if (buggy_status.distance_travelled <= 0.1)
                {
                    buggy_status.set_velocity = 2;
                }
                // if (buggy_status.distance_travelled >= 0.1)
                // {
                //     buggy_status.set_velocity = 0.5;
                // }
                // if (buggy_status.distance_travelled >= 0.4)
                // {
                //     buggy_status.set_velocity = 1;
                // }
                // if (buggy_status.distance_travelled >= 1)
                // {
                //     buggy_status.set_velocity = 0.5;
                // }
                if (buggy_status.distance_travelled >= 0.7)
                {
                    buggy_mode = active_stop;
                    reset_everything();
                }
                break;

            case uturn:
                if (buggy_status.cumulative_angle_deg >= buggy_status.set_angle)
                {
                    if (sensor_array.is_line_detected())
                    {
                        buggy_mode = line_follow_auto;
                        lf_velocity = LINE_FOLLOW_VELOCITY_UTURN;
                    }
                    else 
                    {
                        buggy_status.set_angle += 10;
                    }
                }
                break;
            case line_follow_auto:
                if (sensor_array.is_line_detected())
                {
                    buggy_status.lf_line_last_seen = buggy_status.distance_travelled;
                }
                else if (buggy_status.distance_travelled - buggy_status.lf_line_last_seen >= LINE_FOLLOW_STOP_DISTANCE)
                {
                    // buggy_mode = stop_detect_line;
                    // stop_motors();
                    // float prev_speed = buggy_status.set_velocity;
                    // while (!sensor_array.is_line_detected())
                    // {
                    //     buggy_status.set_velocity = -1;
                    // }
                    // buggy_status.set_velocity = prev_speed;
                }
                break;
            case line_follow: 
                //// comment this disable accel
                // if (buggy_status.is_accelerating)
                // {
                //     float accel_distance = buggy_status.distance_travelled - buggy_status.accel_start_distance;
                //     if (accel_distance > MANUAL_ACCEL_DISTANCE)
                //     {
                //         // pc.printf("SLOWING DOWN\n");
                //         buggy_status.set_velocity = lf_velocity;
                //         buggy_status.accel_start_angle = buggy_status.cumulative_angle_deg;
                //         buggy_status.is_accelerating = false;
                //     }
                //     else
                //     {
                //         // pc.printf("fast\n");
                //         buggy_status.set_velocity = MANUAL_ACCEL_SPEED;
                //     }
                // }
                // else 
                // {
                //     float accel_angle = fabsf(buggy_status.cumulative_angle_deg - buggy_status.accel_start_angle);
                //     // pc.printf("%f\n", accel_angle);
                //     if (accel_angle > MANUAL_ACCEL_ANGLE)
                //     {
                //         // pc.printf("Accelerating!!! %f\n", accel_angle);
                //         buggy_status.set_velocity = MANUAL_ACCEL_SPEED;
                //         buggy_status.accel_start_distance = buggy_status.distance_travelled;
                //         buggy_status.is_accelerating = true;
                //     }
                //     else
                //     {
                //         // pc.printf("slowstuff\n");
                //         buggy_status.set_velocity = lf_velocity;
                //     }
                // }
                break;
            case stop_detect_line:
                if (sensor_array.is_line_detected())
                {
                    buggy_mode = line_follow_auto;
                };
            default:
                break;
        }    
        /* ---  END OF BUGGY ACTIONS/STATE LOGIC CODE  --- */ 

        
        /* --- START OF SERIAL UPDATE CODE --- */
        if (bt_serial_update)
        {
            bt_send_data();
            bt_serial_update = false;
        }

        if (pc_serial_update)
        {
            pc_send_data();
            pc_serial_update = false;
        }
        /* ---  END OF SERIAL UPDATE CODE  --- */


        /*       END OF LOOP      */
        loop_exec_time = global_timer.read_us() - curr_time;
    }
}
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

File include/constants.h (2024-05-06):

/**
 * @file constants.h
 * @brief contains all the constant variables for easy access from one file
 * 
 * All constants are in metres, seconds, hertz unless otherwise stated
 *  
 */

#pragma once

/* PID CONSTANTS */

// General Motor PID constants
#define PID_M_TAU           1
#define PID_M_MIN_OUT       -PID_M_MAX_OUT
#define PID_M_MAX_OUT       1
#define PID_M_MIN_INT       -PID_M_MAX_INT
#define PID_M_MAX_INT       1

// Left Motor (M_L) PID Constants
#define PID_M_L_KP          0.5
#define PID_M_L_KI          7.5
#define PID_M_L_KD          0

// Right Motor (M_R) PID Constants
#define PID_M_R_KP          PID_M_L_KP
#define PID_M_R_KI          PID_M_L_KI
#define PID_M_R_KD          PID_M_L_KD 

// Sensor (S) PID Constants - USED FOR LINE FOLLOW ///////////////////////////
#define PID_S_MIN_OUT       -PID_S_MAX_OUT
#define PID_S_MAX_OUT       1.5
#define PID_S_MIN_INT       -PID_S_MAX_INT
#define PID_S_MAX_INT       0
#define PID_S_KI            0

#define PID_S_TAU           0.001
#define PID_S_KP            0.30
#define PID_S_KD            0.08

// 0.4 0.15 - Oscillates high freq when 0 - might need LP

// Angle (A) PID Constants - USED FOR TURNING
#define PID_A_TAU           0.01
#define PID_A_MIN_OUT       -PID_A_MAX_OUT
#define PID_A_MAX_OUT       0.6
#define PID_A_MIN_INT       -PID_A_MAX_INT
#define PID_A_MAX_INT       0
#define PID_A_KP            0.2
#define PID_A_KI            0.1
#define PID_A_KD            0


/* OTHER CONSTANTS */

// Sensor Array Constants
#define SENS_SAMPLE_COUNT       1   // 5 - 311us, 3 - 195us   
#define SENS_ANGLE_COEFF        1
#define SENS_DETECT_RANGE       0.4

// Line Follow Constants
#define LINE_FOLLOW_VELOCITY        2.1
#define LINE_FOLLOW_VELOCITY_UTURN  2.1
#define LINE_FOLLOW_STOP_DISTANCE   0.3
#define UTURN_ANGLE                 190

#define SLOW_ACCEL_TIME             0.4
#define SLOW_ACCEL_DIVIDER          2

#define STOP_DETECT_TIME            1             // s 

// Unused
#define SLOW_TURNING_GAIN           0                       // Higher Means FASTER
#define SLOW_TURNING_THRESH         2

#define MANUAL_ACCEL_SPEED         0.5
#define MANUAL_ACCEL_DISTANCE      0.5
#define MANUAL_ACCEL_ANGLE         60


// Square Task Constants
#define SQUARE_VELOCITY_SET                 0.4
#define SQUARE_TURNING_RIGHT_ANGLE          92
#define SQUARE_TURNING_LEFT_ANGLE           101.5
#define SQUARE_DISTANCE                     1.01

// Control Timing Constants
#define CONTROL_UPDATE_RATE         2500                                    // Hz
#define CONTROL_UPDATE_PERIOD       (1.0f / CONTROL_UPDATE_RATE)            // Seconds
#define CONTROL_UPDATE_PERIOD_US    (int)(1'000'000 / CONTROL_UPDATE_RATE)  // Micro Seconds

// Control Timing Constants
#define SENSOR_UPDATE_RATE         5000                                    // Hz
#define SENSOR_UPDATE_PERIOD       (1.0f / CONTROL_UPDATE_RATE)            // Seconds
#define SENSOR_UPDATE_PERIOD_US    (int)(1'000'000 / CONTROL_UPDATE_RATE)  // Micro Seconds

// Serial Update Timing Constants
#define SERIAL_UPDATE_PERIOD        0.02     /// Seconds

#define LOG_SIZE                    8'500

// Encoder Constants
#define WHEEL_SEPERATION    0.188       
#define WHEEL_RADIUS        0.0415      
#define PULSE_PER_REV       256         
#define LP_SPEED_B0         0.13575525       
#define LP_SPEED_B1         0.13575525       
#define LP_SPEED_A0         0.7284895      

// 2 Hz Pole Freq:
// Filter coefficients b_i: [0.0591174 0.0591174]
// Filter coefficients a_i: [0.88176521]
// 5 Hz Pole Freq:
// Filter coefficients b_i: [0.13575525 0.13575525]
// Filter coefficients a_i: [0.7284895]
// 7 Hz Pole Freq:
// Filter coefficients b_i: [0.1802684 0.1802684]
// Filter coefficients a_i: [0.63946321]

// Motor Constants
#define MOTOR_PWM_FREQ      20000

// Bluetooth HM10 module default config constants
#define BT_BAUD_RATE        9600

// Maths constant
#define PI                  3.14159265

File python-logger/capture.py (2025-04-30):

from serial.tools import list_ports
from subprocess import call
import serial

import sys
import os
import datetime
import csv
import atexit

serial_port = "COM8"
end_command = b"S"
start_command = b"D"
max_points = 1000
baud = 115200

log_filename: str
data_labels = [
    'time_index',
    'set_point', 
    'measurement', 
    # 'error', 
    'proportional', 
    'integrator', 
    'differentiator', 
    # 'output'
]


def main():
    get_available_ports()
    serialcom = select_port(serial_port)

    setup_log_file()
    print(f"log_file: {log_filename} \n")

    write_first_line()
    serialcom.write(start_command)
    line_read = [False]
    atexit.register(end_function, serialcom, line_read)

    while(True):
        values = get_line(serialcom)
        if values:
            line_read[0] = True
            write_line(values)
    
    

def get_available_ports():
    print("Available Ports:")
    for port in list_ports.comports():
        print(port)
    print(f"Chosen Port: {serial_port}")


def select_port(selected_port):
    try:
        serialCom = serial.Serial(selected_port, baudrate=baud, timeout=0)
        return serialCom
    except serial.serialutil.SerialException:
        print(f"{serial_port} Is invalid")
        exit()


def setup_log_file():
    # Create a folder if it doesn't exist
    folder_name = "logs"
    if not os.path.exists(folder_name):
        os.makedirs(folder_name)

    # Get current date and time
    current_datetime = datetime.datetime.now()
    formatted_datetime = current_datetime.strftime("%Y-%m-%d_%H-%M-%S")

    run_desc = "default"
    if len(sys.argv) >= 2:
        run_desc = ""
        for desc in sys.argv[1:]:
            run_desc += desc

    # Concatenate folder name and filename
    global log_filename
    log_filename = os.path.join(folder_name, f"data_{run_desc}_{formatted_datetime}.csv")
    

def write_first_line():
    with open("data.csv", "w", newline="") as csvfile1, open(log_filename, "w", newline="") as csvfile2:
        writer1 = csv.writer(csvfile1, delimiter=",")
        writer2 = csv.writer(csvfile2, delimiter=",")
        writer1.writerow(data_labels)
        writer2.writerow(data_labels)
        
    
def get_line(serial_comm):
    prev_data = ""
    try:
        while(True):
            line_bytes = serial_comm.readline()
            if not line_bytes:
                continue
            curr_data = prev_data + str(line_bytes.decode("utf-8"))
            if '\n' in curr_data:
                break
            else:
                prev_data = curr_data
        line = curr_data.strip()
        values = line.split(",")
        print(values)
        if len(values) == len(data_labels):
            print(values)
            return values
        else:
            print(line, "<- Data Incomplete and Not Stored")
            return False
        
    except Exception as e:
        print(f"Error: Line Not Read / {e}")


def write_line(val):
    with open("data.csv", "a", newline="") as csvfile1, open(log_filename, "a", newline="") as csvfile2:       
        writer1 = csv.writer(csvfile1, delimiter=",")
        writer2 = csv.writer(csvfile2, delimiter=",")
        writer1.writerow(val)
        writer2.writerow(val)


def end_function(ser, line_read):
    if not line_read[0]:
        os.remove(log_filename)
        print(f"Deleted '{log_filename}' due to 0 data written")
    ser.write(end_command)


if __name__ == "__main__":
    main()

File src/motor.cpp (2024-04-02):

#include "mbed.h"

#include "QEI.h"
#include "motor.h"


Motor::Motor(PinName pwm, PinName dir, PinName bip, PinName CH_A, PinName CH_B, 
             int pulsePerRev, int pwmFreq, int updateRate, float LowPass_a0, float LowPass_b0, float LowPass_b1, float wheelRadius): 
                PWM_pin(pwm), 
                Direction(dir), 
                Bipolar(bip), 
                qei(CH_A, CH_B, NC, pulsePerRev, QEI::X4_ENCODING),
                pulse_per_rev(pulsePerRev),
                pwm_freq(pwmFreq),
                update_rate(updateRate), 
                LP_a0(LowPass_a0),
                LP_b0(LowPass_b0),
                LP_b1(LowPass_b1),
                wheel_radius(wheelRadius)
{
    PWM_pin.period(1.0 / pwm_freq);
    set_direction(1);
    set_bipolar_mode(false);
    set_duty_cycle(0);

    prev_tick_count = 0;
    speed = 0;
    prev_speed = 0;
    filtered_speed = 0;
    prev_filtered_speed = 0;
};

void Motor::update(void)
{
    // update pulse diff
    curr_tick_count = qei.getPulses();
    int tick_diff = curr_tick_count - prev_tick_count;
    prev_tick_count = curr_tick_count;

    // update rotational freq
    rotational_freq = ((float) tick_diff / (4 * pulse_per_rev)) * update_rate;

    // update rpm
    rpm = rotational_freq * 60;

    // calculate raw speed
    speed = 2 * pi * wheel_radius * rotational_freq;

    // low pass filter for speed
    filtered_speed = (prev_filtered_speed * LP_a0) + (speed * LP_b0) + (prev_speed * LP_b1);

    prev_filtered_speed = filtered_speed;
    prev_speed = speed;
}

void Motor::reset(void)
{
    qei.reset();

    curr_tick_count = 0;
    prev_tick_count = 0;
    rotational_freq = 0;
    speed = 0;
    filtered_speed = 0;
    prev_speed = 0;
    prev_filtered_speed = 0;
    rpm = 0;
}

void Motor::set_duty_cycle(float DutyCycle)
{
    duty_cycle = DutyCycle;
    if (duty_cycle < 0.0)
    {
        duty_cycle = -duty_cycle;
        set_direction(0);
    }
    else
    {
        set_direction(1);
    }
    PWM_pin.write(1 - duty_cycle);
};

void Motor::set_direction(bool DirState)
{
    Direction.write(DirState);
    direction = DirState;
};
    
void Motor::set_bipolar_mode(bool BipState)
{
    Bipolar.write(BipState);
    bipolar = BipState; 
};

bool Motor::get_direction(void)
{
    return direction;
};

bool Motor::get_bipolar_mode(void)
{
    return bipolar;
};

float Motor::get_duty_cycle(void)
{
    return duty_cycle;
};

int Motor::get_tick_count(void)
{
    return curr_tick_count;
}

float Motor::get_rotational_freq(void)
{
    return rotational_freq;
}

float Motor::get_rpm(void)
{
    return rpm;
}

float Motor::get_speed(void)
{
    return speed;
}

float Motor::get_filtered_speed(void)
{
    return filtered_speed;
}

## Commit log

2024-02-12 motor.h added
2024-02-14 PID.h added
2024-02-16 Fixed formatting of header file and added seperate source cpp file
    [constants.h, main.cpp, motor.cpp]
2024-02-16 Merging latest bluetooth to main and fixed conflicts
    [bluetooth.cpp, main.cpp, pin_assignments.h]
2024-02-16 added encoder class and few lines in main to test the encoder
2024-02-16 Fixed some stuff with timer
    [main.cpp]
2024-02-17 fixed the formula for angle calculation
    [constants.h, main.cpp, motor.cpp]
2024-02-17 Updated new pinouts for encoders
2024-02-17 added motor driver board class to control en pin, battery monitor is wip
2024-02-20 Theres going to be a lot of copy pasting ugly code to check all the case
2024-02-20 structured the PID library
2024-02-20 Improved PID class and streamlined variable names
2024-02-20 made the framework to complete the square task. The logic is WIP
2024-02-20 Added few temporary lines for debugging PID and test other tasks
2024-02-22 bugfixes, added control for serial updates timing
    [bluetooth.cpp, constants.h, main.cpp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]
2024-02-23 fixed small bugs with ticker not working
    [constants.h, main.cpp]
2024-02-23 created a simple code for square task wihout PID.
2024-02-23 changed to two wheel for turning in square test
2024-02-28 Lots of updates, motor/angle PID, low pass speed and other features.
2024-02-29 changed square task to use PID control
2024-03-06 added sensor class
2024-03-07 added sensor stuff
2024-03-08 added led control and sampling average reading for the sensor class
2024-03-08 streamlined naming for sensor data members to 0 to 5
2024-03-10 combined and removed encoder/vp class. simplifictions of main.cpp
2024-03-11 added measurement of current and voltage of the board n reorganise
2024-03-12 bugfixes for the driverboard readings
    [constants.h, main.cpp, motor_driver_board.cpp]
2024-03-14 Post First Lab Code. Fixed bugs and speed limit to .9 DC
    [constants.h, main.cpp]
2024-03-26 code used for motor pid tuning
2024-04-01 removed dependency of constants.h from motor.cpp
2024-04-05 small reorganise and changed lp filter constants
2024-04-11 commented bluetooth and driverboard class
2024-04-12 reverting to a working code (hopefully)
    [constants.h, main.cpp]
2024-04-12 working but the stop line is not consistent at track
2024-04-12 streamlined the sensor output
2024-04-19 seperated Angle and Sensor PID
2024-04-25 few changes but still unstable
    [constants.h, main.cpp]
2024-04-25 NEED SENSOR PID TUNING. added a LP filter which idk might caused problem
    [constants.h, main.cpp]
2024-04-26 Added Bluetooth PID adjustment
2024-04-26 added untested accel function and sensor calibration
2024-04-27 Added initial min n max calibration
2024-04-27 switched to a new speed offset algorithm
2024-04-29 adding seperate sensor ISR update with double rate. works 2ms with tilt
2024-05-01 moved sensor pid to correct ISR
    [main.cpp]
2025-04-30 added the python script for logging to the repo
    [data.csv]
2025-04-30 added all files related to the project as archive and updated README
    [10mm M3 Standoffs.SLDPRT, 30_deg_ramp.SLDPRT, 30_deg_ramp.STEP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]
